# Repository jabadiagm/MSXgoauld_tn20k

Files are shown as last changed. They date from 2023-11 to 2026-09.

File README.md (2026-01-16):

# MSXgoauld_tn20k

> [WARNING]
> This repository is outdated and kept for reference only. Last version is here: https://github.com/jabadiagm/MSXgoauldSD_tn20k
>

MSX Goa'uld board with Tang Nano 20k

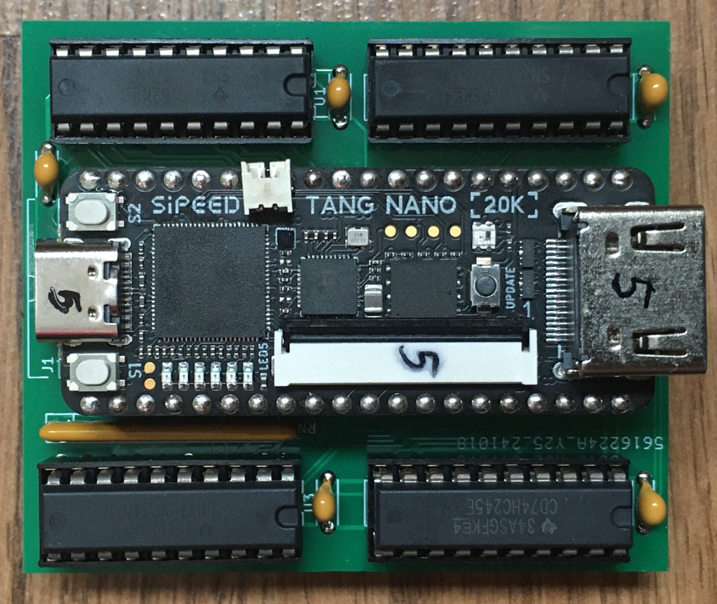
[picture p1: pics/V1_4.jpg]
V1.4_DIP

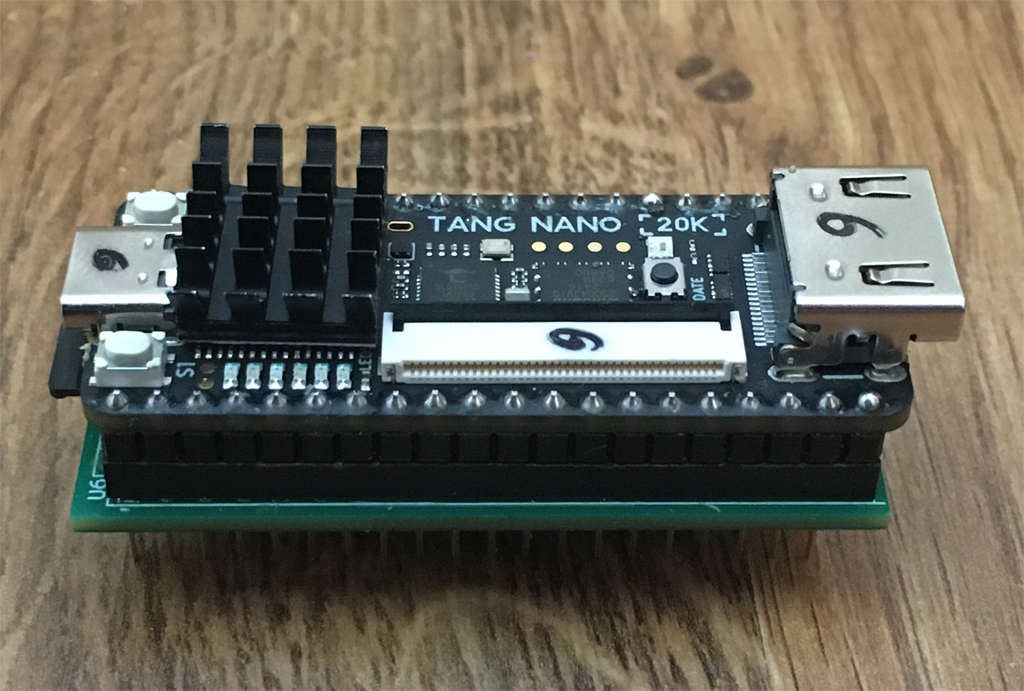
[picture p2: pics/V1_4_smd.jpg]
V1.4_SMD

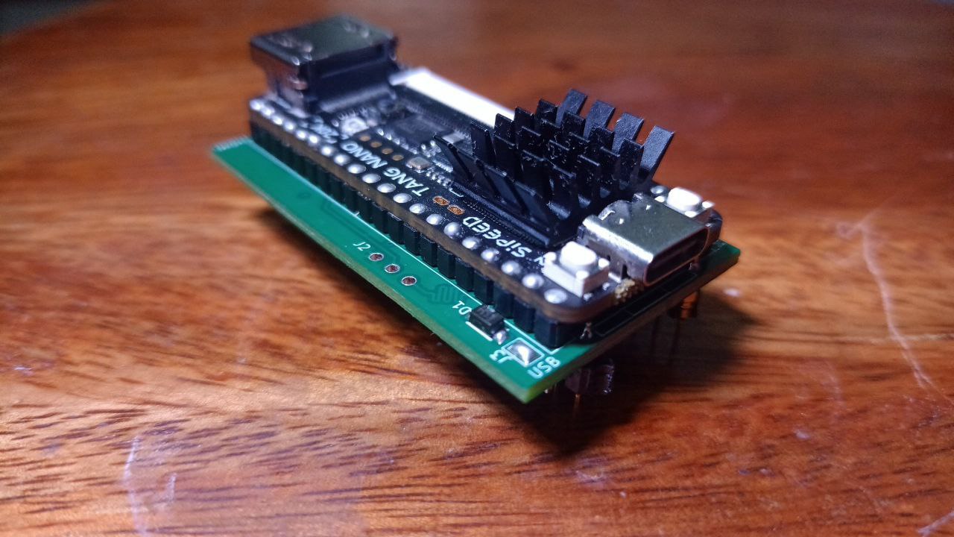
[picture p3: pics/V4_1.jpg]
V4.1_SMD


MSX2+ engine in Z80 socket. It turns one MSX into an MSX2+ by replacing Z80 processor. FPGA in board contains: 
* Z80
* V9958 with hdmi output
* MSX2+ BIOS
* 4MB mapper
* RTC
* PSG through hdmi
* OPLL through hdmi
* SCC (audio only) through hdmi

## How it works
Logic acts on bus control signals so that internal devices inside fpga take priority over external devices. 

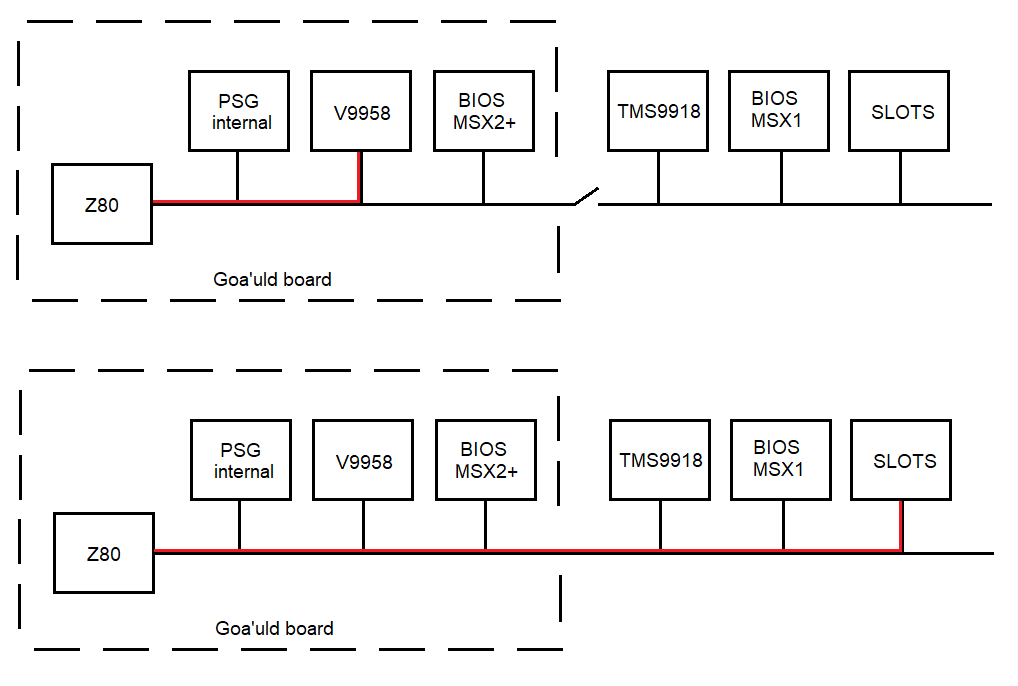
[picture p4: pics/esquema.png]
Esquema


## Boards

There are two lines of boards, 1.4 (by Palver, DIP & SMD) and 4.1 (by Chandler, SMD). Main difference is the orientation of the hdmi connector, to the same side of Z80's pin 1 (4.1) or the opposite (1.4). Revisions 2, 3, 4 are outdated and kept for reference only. 

Mind Revision 4.1 uses 74LVC245 in U5. Although their technical information tells they require 3.3V to operate, they are also 5V tolerant. This has been tested and considered safe. Check https://github.com/jabadiagm/MSXgoauld_tn20k/issues/15 for more information. 

BOM for the 1.4 DIP board:

```
Qty| Name                        | Ref
--------------------------------------------------
 2 | Latch                       | SN74HC373N
 2 | Bus transceiver             | SN74LVC245AN
 1 | Bus transceiver             | CD74HC245E
 6 | Capacitor 100 nF            | Aliexpress
 1 | Schottky Diode              | 1N5817
 1 | Resistor network 8x10K      | 4609X-101-103LF
 2 | Female header 20p 2.54      | Aliexpress
 1 | Male header 40p 2.54 turned | Aliexpress
 5 | Socket DIP 20               | ICVT-20P
 1 | Tang Nano 20K               | Aliexpress
 ```

## Slot map

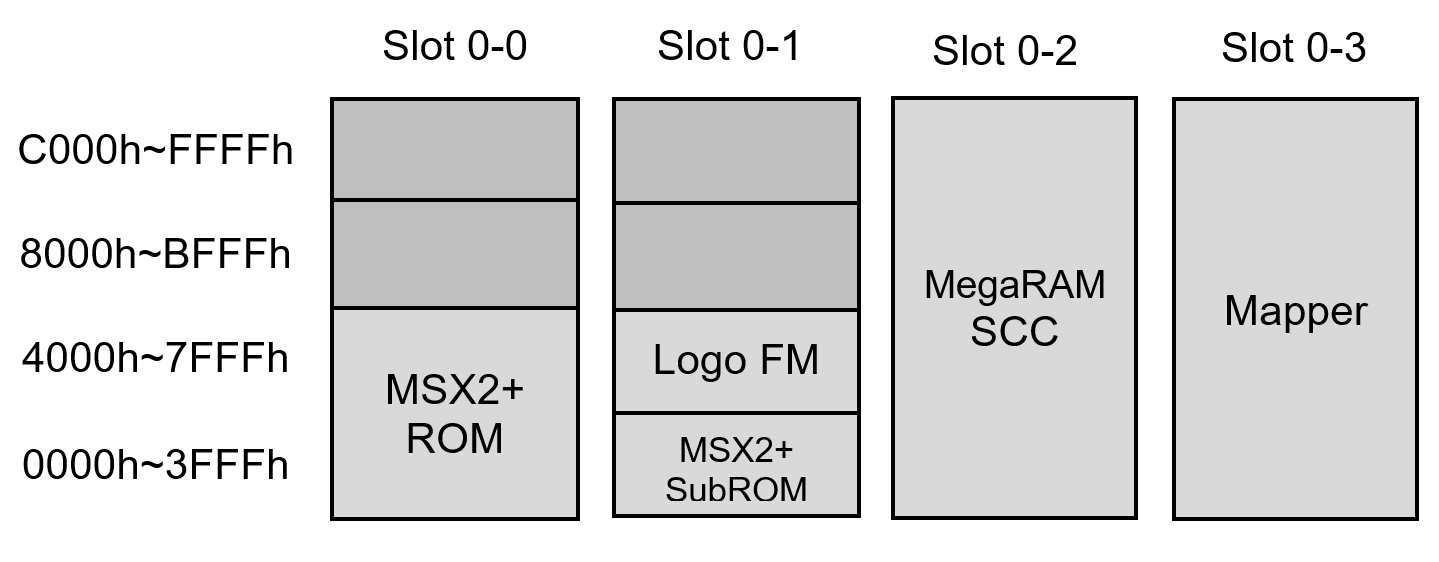
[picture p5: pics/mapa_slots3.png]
Slot map


Mapper can be relocated to slots 1, 2, or 3 using config menu.

## Update from previous hardware (V1, V2, V3, V4)
* Replace U1, U2 -> 74HC373, U5 -> 74HC245
* Solder a 10K resistor array to data bus lines, pulled up to 5V
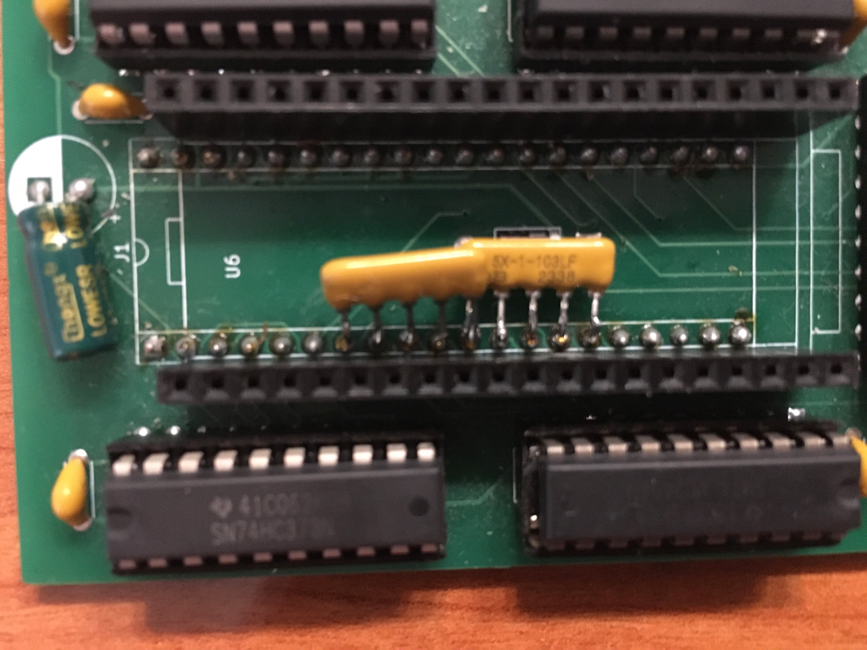
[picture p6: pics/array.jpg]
Array


## SCC audio
SCC is located in Slot 0-2 to use with sofarun, using these settings:

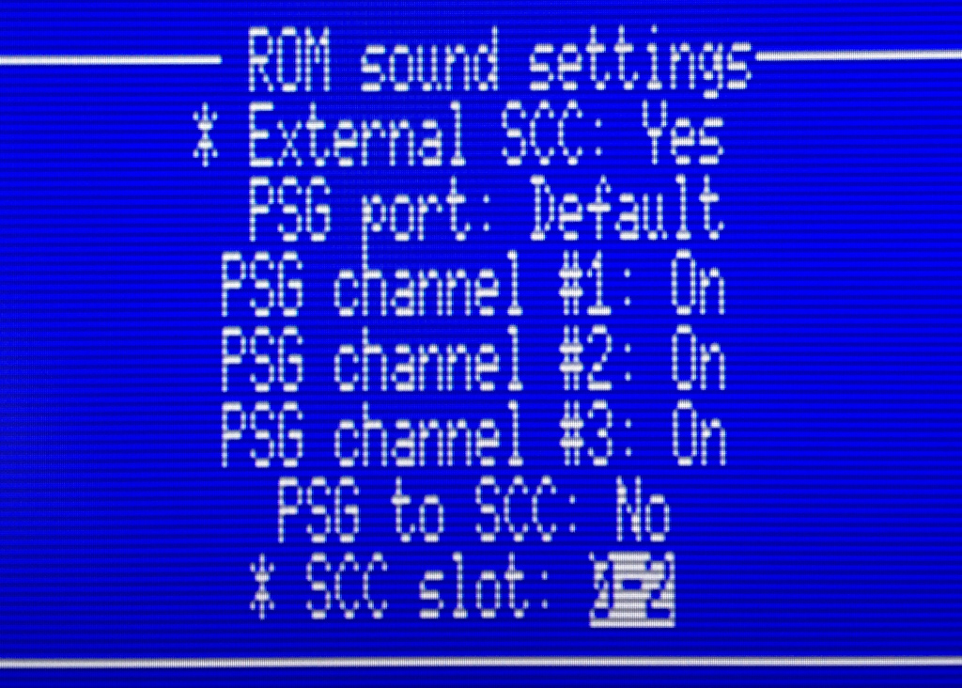
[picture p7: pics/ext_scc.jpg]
ext_scc


## Configuration
Config menu is showed pressing g during MSX logo. New improved menu is created by [nataliapc](https://github.com/nataliapc/msx_goauld_settings_menu)

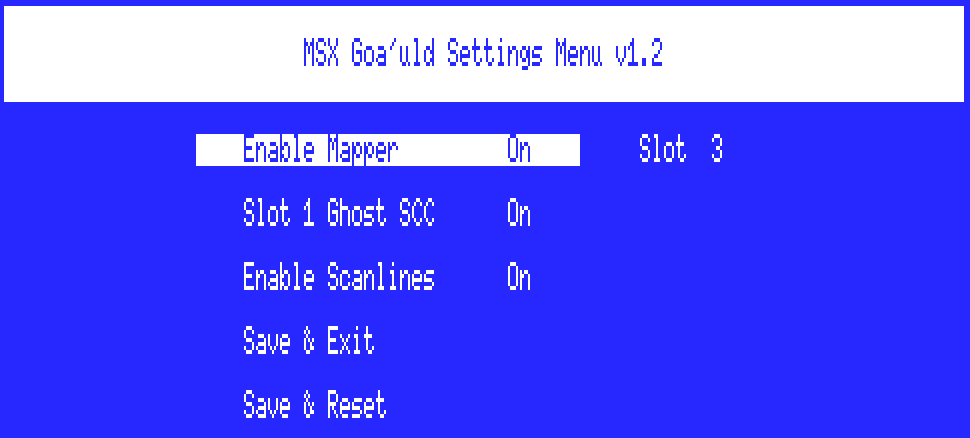
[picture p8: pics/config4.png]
Config


* Enable Mapper: On by default. Disable when having compatibility issues or to use a different mapper
* Mapper Slot: 0 by default. Change to 1-3 to get mapper in a not expanded slot (best compatibility). Physical slot will be disabled
* Slot 1 Ghost SCC: Off by default. Enable to get sound from an SCC cartridge located in slot 1
* Enable Scanlines: On by default. Disable to get a clean hdmi picture
* Save & Exit: store new config and continue, changes in mapper settings will be effective after pressing reset
* Save & Reset: store new config and make software reset, changes will be immediate

## Slots dance
Goa'uld has four internal slots available. As with other modules, internal slots take priority over physical ones. This means that when a device is using internal slot n, then physical slot n is disabled  and any cartridge in that slot will not be detected. 
By default, BIOS and mapper occupy internal slot 0, leaving physical slots 1 to 3 available for cartridges. However, this default layout can cause compatibility issues with some software, such as tape games. 
To resolve these issues, you can move the mapper from expanded slot 0 to one of the non-expanded internal slots (1, 2, or 3). This adjustment can solve many compatibility problems.

## Known issues
* Reset from config menu is not compatible with some hardware. Use physical reset button when possible
* Multimente: shows garbage characters. Move internal mapper to slots 1, 2 or 3
* Tape games fail: move internal mapper to slots 1, 2 or 3
* Noises when loading a rom with sofarun: change sofarun settings to use mapper for that rom
* Carnivore C2 software reset is not compatible with goa'uld

> [!WARNING]
> Not yet fully working on all MSX!
>

## HDMI wiring
Use a flat cable with detachable connectors, like [this](https://a.aliexpress.com/_Ex8dto0) or [this](https://s.click.aliexpress.com/e/_oEFYFU9)

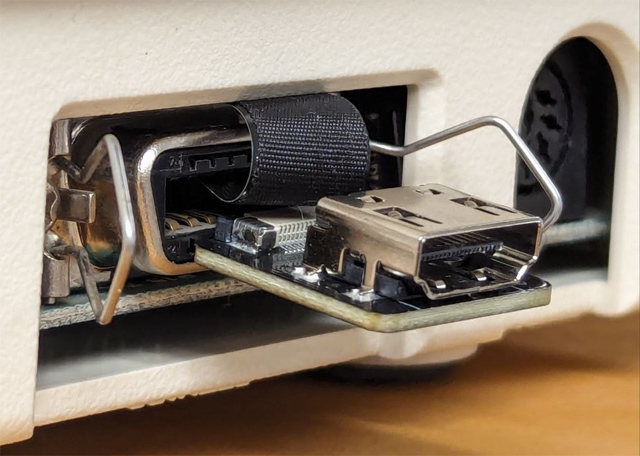
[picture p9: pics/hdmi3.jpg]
hdmi


Find some examples [here](https://makerworld.com/es/models/1246988-hdmi-cover-using-printer-port-for-msx-goauld) and [here](https://www.thingiverse.com/thing:6990854)

Toshiba HX-10 has proven to be a nice choice for Goa'uld board. There are some mods to get hdmi connector and even a reset button on the side panel. An example [here](https://www.thingiverse.com/thing:6932728)

### Tips
* Try a proven board first to check if your msx is compatible
* Get integrated circuits from trusted sources
* Use a heatsink when possible
* Use turned pins in header to avoid damages in Z80 socket
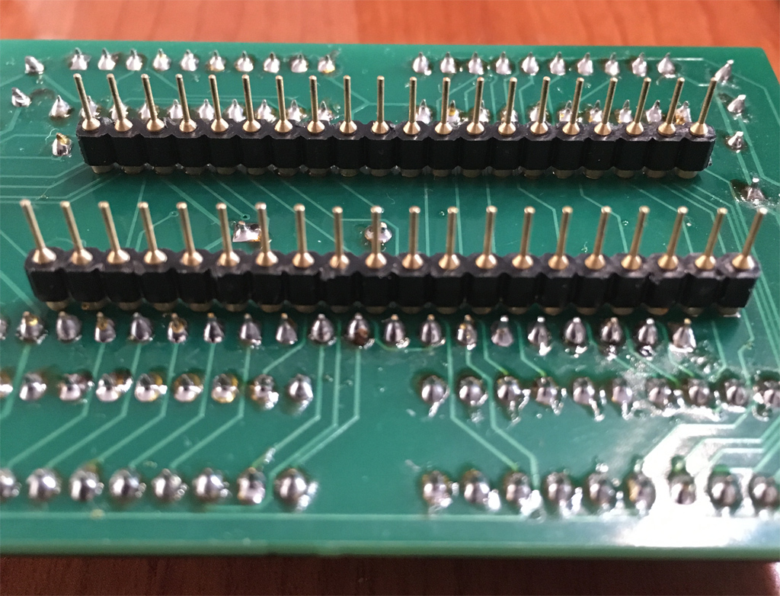
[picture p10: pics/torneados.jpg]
turned header

* Board is sensitive to dirty electrical contacts, way more than Z80. Keep cartridge & Z80 socket contacts clean
* When soldering headers, start with the inner one (Z80)
* When using an extension wire, plug tang to 5V

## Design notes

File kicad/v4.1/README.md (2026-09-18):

# Revision 4.1

4.1 Revision shrinks revision 4.0 by removing the external voltage regulator, which is not necessary anymore. This revision also adds 100nF decoupling capacitors for buffers/latches ICs and places pull-up resistors for data bus wires.

V4.1_SMD

## BOM

Check our [Interactive BOM](https://html-preview.github.io/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) to have better details.                                                       

| Reference | Chip | Value |
|:-----:|:-----:|:-----:|
| U1~U2 | 74HCT373 (TSSOP-20) | - |
| U3~U4 | 74LVC245 (TSSOP-20) | - |
| U5 | 74HC245 (TSSOP-20) | - |
| U6 | Tang Nano 20k | - |
| D1* | DSS32 (SOD123FL) | - |
| C4~C8 | 0603 SMD Capacitor | $\mathsf{100\ nF}$ |
| R1 | Resistor (0603) | $\mathsf{10\ k\Omega}$ |
| R2~R3 | 4xResistor Array (0603) | $\mathsf{16\ k\Omega}$ |

## Assembly

Production files (gerbers, assembly, placement...) can be found in `production` folder

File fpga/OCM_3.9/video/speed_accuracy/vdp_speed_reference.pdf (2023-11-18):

“MOST COMMON REFERENCE FOR THE VDP SPEED ACCURACY”

PANASONIC FS-A1GT MSX turbo R / R800 (Z80 MODE) / VDP V9958

The tables for the copies:

LMMM accuracy: 16 | HMMM accuracy: 32 | YMMM accuracy: 32
TESTCOPY FS-A1GT X=32 | TESTCOPY FS-A1GT X=64 | TESTCOPY FS-A1GT X=64
Spr / Lin - Speed 50/60Hz | Spr / Lin - Speed 50/60Hz | Spr / Lin - Speed 50/60Hz
on / 212 - 1232 / 976 | on / 212 - 3520 / 2784 | on / 212 - 4192 / 3168
on / 192 - 1264 / 1008 | on / 192 - 3616 / 2880 | on / 192 - 4384 / 3360
off / 212 - 1584 / 1312 | off / 212 - 4352 / 3616 | off / 212 - 5856 / 4832
off / 192 - 1584 / 1312 | off / 192 - 4384 / 3648 | off / 192 - 5856 / 4864
--Blank-- - 1600 / 1328 | --Blank-- - 4512 / 3744 | --Blank-- - 6112 / 5120

The tables for the fills:

LMMV accuracy: 16 | HMMV accuracy: 64
TESTCOPY FS-A1GT X=32 | TESTCOPY FS-A1GT X=128
Spr / Lin - Speed 50/60Hz | Spr / Lin - Speed 50/60Hz
on / 212 - 1696 / 1344 | on / 212 - 7040 / 5632
on / 192 - 1728 / 1392 | on / 192 - 7168 / 5760
off / 212 - 1840 / 1488 | off / 212 - 7232 / 5888
off / 192 - 1856 / 1504 | off / 192 - 7360 / 5952
--Blank-- - 2128 / 1776 | --Blank-- - 8448 / 7040

The table for the lines:

LINE accuracy: 32
TESTCOPY FS-A1GT X=8 Y=8

Spr / Lin - Speed 50/60Hz

on / 212 - | 3936 | / | 3264
on / 192 - | 3968 | / | 3296
off / 212 - | 4096 | / | 3392
off / 192 - | 4096 | / | 3392
--Blank-- - | 4224 | / | 3520
( on / 212 )

Notes:

- Speed is indicated in bytes per interrupt.
- On “TestCopy” program LINES = SPEED / ACCURACY.
- The CPU frequency for the test is 3.58MHz.

The above values have been verified by KdL, 2018.05.14 These information refers to: http://map.grauw.nl/articles/vdp_commands_speed.php

More information to get the most accurate LINE speed (not yet implemented in OCM): http://map.grauw.nl/articles/vdp-vram-timing/vdp-timing.htmlhttp://map.grauw.nl/articles/vdp-vram-timing/vdp-timing-2.html

“MOST COMMON REFERENCE FOR THE VDP SPEED ACCURACY”

PHILIPS NMS-8245 MSX2 / Z80 / VDP V9938

The tables for the copies:

LMMM accuracy: 16 | HMMM accuracy: 32 | YMMM accuracy: 32
TESTCOPY NMS-8245 X=32 | TESTCOPY NMS-8245 X=64 | TESTCOPY NMS-8245 X=64
Spr / Lin - Speed 50/60Hz | Spr / Lin - Speed 50/60Hz | Spr / Lin - Speed 50/60Hz
on / 212 - 1232 / 976 | on / 212 - 3520 / 2784 | on / 212 - 4192 / 3168
on / 192 - 1264 / 1008 | on / 192 - 3616 / 2880 | on / 192 - 4384 / 3360
off / 212 - 1584 / 1312 | off / 212 - 4352 / 3616 | off / 212 - 5856 / 4832
off / 192 - 1584 / 1312 | off / 192 - 4384 / 3648 | off / 192 - 5856 / 4864
--Blank-- - 1600 / 1328 | --Blank-- - 4512 / 3744 | --Blank-- - 6112 / 5120

The tables for the fills:

LMMV accuracy: 16 | HMMV accuracy: 64
TESTCOPY NMS-8245 X=32 | TESTCOPY NMS-8245 X=128
Spr / Lin - Speed 50/60Hz | Spr / Lin - Speed 50/60Hz
on / 212 - 1696 / 1344 | on / 212 - 7040 / 5632
on / 192 - 1728 / 1392 | on / 192 - 7168 / 5760
off / 212 - 1840 / 1488 | off / 212 - 7232 / 5888
off / 192 - 1856 / 1504 | off / 192 - 7360 / 5952
--Blank-- - 2128 / 1776 | --Blank-- - 8448 / 7040

The table for the lines:

LINE accuracy: 32
TESTCOPY NMS-8245 X=8 Y=8

Spr / Lin - Speed 50/60Hz

on / 212 - | 4096 | / | 3392
on / 192 - | 4128 | / | 3424
off / 212 - | 4224 | / | 3520
off / 192 - | 4256 | / | 3520
--Blank-- - | 4352 | / | 3648
( on / 212 )

Notes:

- Speed is indicated in bytes per interrupt.
- On “TestCopy” program LINES = SPEED / ACCURACY.
- The CPU frequency for the test is 3.58MHz.

The above values have been verified by KdL, 2018.05.14 These information refers to: http://map.grauw.nl/articles/vdp_commands_speed.php

More information to get the most accurate LINE speed (not yet implemented in OCM): http://map.grauw.nl/articles/vdp-vram-timing/vdp-timing.htmlhttp://map.grauw.nl/articles/vdp-vram-timing/vdp-timing-2.html

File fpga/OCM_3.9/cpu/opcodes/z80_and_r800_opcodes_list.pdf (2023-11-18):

## Z80 And R800 Opcodes List

### Opcodes on single-byte

| 00 | 01 | 02 | 03 | 04 | 05 | 06 | 07 | 08 | 09 | 0A | 0B | 0C | 0D | 0E | 0F
00 | NOP | LD BC,ad | LD (BC),A | INC BC | INC B | DEC B | LD B,v | RLCA | EX AF,AF' | ADD HL,BC | LD A,(BC) | DEC BC | INC C | DEC C | LD C,v | RRCA
10 | DJNZ v | LD DE,ad | LD (DE),A | INC DE | INC D | DEC D | LD D,v | RLA | JR v | ADD HL,DE | LD A,(DE) | DEC DE | INC E | DEC E | LD E,v | RRA
20 | JR nz,v | LD HL,ad | LD (ad),HL | INC HL | INC H | DEC H | LD H,v | DAA | JR z,v | ADD HL,HL | LD HL,(ad) | DEC HL | INC L | DEC L | LD L,v | CPL
30 | JR nc,v | LD SP,ad | LD (ad),A | INC SP | INC (HL) | DEC (HL) | LD (HL),v | SCF | JR C,v | ADD HL,SP | LD A,(ad) | DEC SP | INC A | DEC A | LD A,v | CCF
40 | LD B,B | LD B,C | LD B,D | LD B,E | LD B,H | LD B,L | LD B,(HL) | LD B,A | LD C,B | LD C,C | LD C,D | LD C,E | LD C,H | LD C,L | LD C,(HL) | LD C,A
50 | LD D,B | LD D,C | LD D,D | LD D,E | LD D,H | LD D,L | LD D,(HL) | LD D,A | LD E,B | LD E,C | LD E,D | LD E,E | LD E,H | LD E,L | LD E,(HL) | LD E,A
60 | LD H,B | LD H,C | LD H,D | LD H,E | LD H,H | LD H,L | LD H,(HL) | LD H,A | LD L,B | LD L,C | LD L,D | LD L,E | LD L,H | LD L,L | LD L,(HL) | LD L,A
70 | LD (HL),B | LD (HL),C | LD (HL),D | LD (HL),E | LD (HL),H | LD (HL),L | HALT | LD (HL),A | LD A,B | LD A,C | LD A,D | LD A,E | LD A,H | LD A,L | LD A,(HL) | LD A,A
80 | ADD A,B | ADD A,C | ADD A,D | ADD A,E | ADD A,H | ADD A,L | ADD A,(HL) | ADD A,A | ADC A,B | ADC A,C | ADC A,D | ADC A,E | ADC A,H | ADC A,L | ADC A,(HL) | ADC A,A
90 | SUB B | SUB C | SUB D | SUB E | SUB H | SUB L | SUB (HL) | SUB A | SBC A,B | SBC A,C | SBC A,D | SBC A,E | SBC A,H | SBC A,L | SBC A,(HL) | SBC A
A0 | AND B | AND C | AND D | AND E | AND H | AND L | AND (HL) | AND A | XOR B | XOR C | XOR D | XOR E | XOR H | XOR L | XOR (HL) | XOR A
B0 | OR B | OR C | OR D | OR E | OR H | OR L | OR (HL) | OR A | CP B | CP C | CP D | CP E | CP H | CP L | CP (HL) | CP A
C0 | RET nz | POP BC | JP nz,ad | JP ad | CALL nz,ad | PUSH BC | ADD A,v | RST 0h | RET z | RET | JP z,ad | * | CALL z,ad | CALL ad | ADC A,v | RST 8h
D0 | RET nc | POP DE | JP nc,ad | OUT (v),A | CALL nc,ad | PUSH DE | SUB v | RST 10h | RET c | EXX | JP c,ad | IN A,(v) | CALL c,ad | ** | SBC A,v | RST 18h
E0 | RET po | POP HL | JP po,ad | EX (SP),HL | CALL po,ad | PUSH HL | AND v | RST 20h | RET pe | JP (HL) | JP pe,ad | EX DE,HL | CALL pe,ad | *** | XOR v | RST 28h
F0 | RET p | POP AF | JP p,ad | DI | CALL p,ad | PUSH AF | OR v | RST 30h | RET m | LD SP,HL | JP m,ad | EI | CALL m,ad | **** | CP v | RST 38h

Note: Some of these opcodes are followed by one or two bytes to specify the value v or the address ad.

### (*) Opcodes extended on 2-byte which begin with CBh

CB | 00 | 01 | 02 | 03 | 04 | 05 | 06 | 07 | 08 | 09 | 0A | 0B | 0C | 0D | 0E | 0F
00 | RLC B | RLC C | RLC D | RLC E | RLC H | RLC L | RLC (HL) | RLC A | RRC B | RRC C | RRC D | RRC E | RRC H | RRC H | RRC (HL) | RRC A
10 | RL B | RL C | RL D | RL E | RL H | RL L | RL (HL) | RL A | RR B | RR C | RR D | RR E | RR H | RR H | RR (HL) | RR A
20 | SLA B | SLA C | SLA D | SLA E | SLA H | SLA L | SLA (HL) | SLA A | SRA B | SRA C | SRA D | SRA E | SRA H | SRA H | SRA (HL) | SRA A
30 | SLL B | SLL C | SLL D | SLL E | SLL H | SLL L | SLL (HL) | SLL A | SRL B | SRL C | SRL D | SRL E | SRL H | SRL H | SRL (HL) | SRL A
40 | BIT 0,B | BIT 0,C | BIT 0,D | BIT 0,E | BIT 0,H | BIT 0,L | BIT 0,(HL) | BIT 0,A | BIT 1,B | BIT 1,C | BIT 1,D | BIT 1,E | BIT 1,H | BIT 1,L | BIT 1,(HL) | BIT 1,A
50 | BIT 2,B | BIT 2,C | BIT 2,D | BIT 2,E | BIT 2,H | BIT 2,L | BIT 2,(HL) | BIT 2,A | BIT 3,B | BIT 3,C | BIT 3,D | BIT 3,E | BIT 3,H | BIT 3,L | BIT 3,(HL) | BIT 3,A
60 | BIT 4,B | BIT 4,C | BIT 4,D | BIT 4,E | BIT 4,H | BIT 4,L | BIT 4,(HL) | BIT 4,A | BIT 5,B | BIT 5,C | BIT 5,D | BIT 5,E | BIT 5,H | BIT 5,L | BIT 5,(HL) | BIT 5,A
70 | BIT 6,B | BIT 6,C | BIT 6,D | BIT 6,E | BIT 6,H | BIT 6,L | BIT 6,(HL) | BIT 6,A | BIT 7,B | BIT 7,C | BIT 7,D | BIT 7,E | BIT 7,H | BIT 7,L | BIT 7,(HL) | BIT 7,A
80 | RES 0,B | RES 0,C | RES 0,D | RES 0,E | RES 0,H | RES 0,L | RES 0,(HL) | RES 0,A | RES 1,B | RES 1,C | RES 1,D | RES 1,E | RES 1,H | RES 1,L | RES 1,(HL) | RES 1,A
90 | RES 2,B | RES 2,C | RES 2,D | RES 2,E | RES 2,H | RES 2,L | RES 2,(HL) | RES 2,A | RES 3,B | RES 3,C | RES 3,D | RES 3,E | RES 3,H | RES 3,L | RES 3,(HL) | RES 3,A
A0 | RES 4,B | RES 4,C | RES 4,D | RES 4,E | RES 4,H | RES 4,L | RES 4,(HL) | RES 4,A | RES 5,B | RES 5,C | RES 5,D | RES 5,E | RES 5,H | RES 5,L | RES 5,(HL) | RES 5,A
B0 | RES 6,B | RES 6,C | RES 6,D | RES 6,E | RES 6,H | RES 6,L | RES 6,(HL) | RES 6,A | RES 7,B | RES 7,C | RES 7,D | RES 7,E | RES 7,H | RES 7,L | RES 7,(HL) | RES 7,A
C0 | SET 0,B | SET 0,C | SET 0,D | SET 0,E | SET 0,H | SET 0,L | SET 0,(HL) | SET 0,A | SET 1,B | SET 1,C | SET 1,D | SET 1,E | SET 1,H | SET 1,L | SET 1,(HL) | SET 1,A
D0 | SET 2,B | SET 2,C | SET 2,D | SET 2,E | SET 2,H | SET 2,L | SET 2,(HL) | SET 2,A | SET 3,B | SET 3,C | SET 3,D | SET 3,E | SET 3,H | SET 3,L | SET 3,(HL) | SET 3,A
E0 | SET 4,B | SET 4,C | SET 4,D | SET 4,E | SET 4,H | SET 4,L | SET 4,(HL) | SET 4,A | SET 5,B | SET 5,C | SET 5,D | SET 5,E | SET 5,H | SET 5,L | SET 5,(HL) | SET 5,A
F0 | SET 6,B | SET 6,C | SET 6,D | SET 6,E | SET 6,H | SET 6,L | SET 6,(HL) | SET 6,A | SET 7,B | SET 7,C | SET 7,D | SET 7,E | SET 7,H | SET 7,L | SET 7,(HL) | SET 7,A

### (**) Opcodes extended on two-byte which begin with DDh (for register IX)

DD | 00 | 01 | 02 | 03 | 04 | 05 | 06 | 07 | 08 | 09 | 0A | 0B | 0C | 0D | 0E | 0F
00 | | | | | | | | | | ADD IX,BC
10 | | | | | | | | | | ADD IX,DE
20 | | LD IX,ad | LD (ad),IX | INC IX | INC IXH | DEC IXH | LD IXH,v | | | ADD IX,IX | LD IX,(ad) | DEC IX | INC IXL | DEC IXL | LD IXL,v
30 | | | | | INC (IX+v) | DEC (IX+v) | LD (IX+v),v | | | ADD IX,SP
40 | | | | | LD B,IXH | LD B,IXL | LD B,(IX+v) | | | | | | LD C,IXH | LD C,IXL | LD C,(IX+v)
50 | | | | | LD D,IXH | LD D,IXL | LD D,(IX+v) | | | | | | LD E,IXH | LD E,IXL | LD E,(IX+v)
60 | LD IXH,B | LD IXH,C | LD IXH,D | LD IXH,E | LD IXH,IXH | LD IXH,IXL | LD H,(IX+v) | LD IXH,A | LD IXL,B | LD IXL,C | LD IXL,D | LD IXL,E | LD IXL,IXH | LD IXL,IXL | LD L,(IX+v) | LD IXL,A
70 | LD (IX+v),B | LD (IX+v),C | LD (IX+v),D | LD (IX+v),E | LD (IX+v),H | LD (IX+v),L | | LD (IX+v),A | | | | | LD A,IXH | LD A,IXL | LD A,(IX+v)
80 | | | | | ADD A,IXH | ADD A,IXL | ADD A,(IX+v) | | | | | | ADC A,IXH | ADC A,IXL | ADC A,(IX+v)
90 | | | | | SUB IXH | SUB IXL | SUB (IX+v) | | | | | | SBC A,IXH | SBC A,IXL | SBC A,(IX+v)
A0 | | | | | AND IXH | AND IXL | AND (IX+v) | | | | | | XOR IXH | XOR IXL | XOR (IX+v)
B0 | | | | | OR IXH | OR IXL | OR (IX+v) | | | | | | CP IXH | CP IXL | CP (IX+v)
C0 | | | | | | | | | | | | **²

D0
E0 | | POP IX | | EX (SP),IX | | PUSH IX | | | | JP (IX)
F0 | | | | | | | | | | LD SP,IX

Note: Some of these opcodes are followed by one or two bytes to specify the value v or the address ad.

### (**²) Opcodes extended on four-byte which begin with DDh+CBh+v (for register IX)

DD+CB+v | 00 | 01 | 02 | 03 | 04 | 05 | 06 | 07 | 08 | 09 | 0A | 0B | 0C | 0D | 0E | 0F
00 | RLC (v+IX) LD B,(v+IX) | RLC (IX+v) LD C,(IX+v) | RLC (v+IX) LD D,(v+IX) | RLC (v+IX) LD E,(v+IX) | RLC (v+IX) LD H,(v+IX) | RLC (v+IX) LD L,(v+IX) | RLC (v+IX) | RLC (v+IX) LD A,(v+IX) | RRC (v+IX) LD B,(v+IX) | RRC (v+IX) LD C,(v+IX) | RRC (v+IX) LD D,(v+IX) | RRC (v+IX) LD E,(v+IX) | RRC (v+IX) LD H,(v+IX) | RRC (v+IX) LD L,(v+IX) | RRC (v+IX) | RRC (v+IX) LD A,(v+IX)
10 | RL (v+IX) LD B,(v+IX) | RL (IX+v) LD C,(IX+v) | RL (v+IX) LD D,(v+IX) | RL (v+IX) LD E,(v+IX) | RL (v+IX) LD H,(v+IX) | RL (v+IX) LD L,(v+IX) | RL (v+IX) | RL (v+IX) LD A,(v+IX) | RR (v+IX) LD B,(v+IX) | RR (v+IX) LD C,(v+IX) | RR (v+IX) LD D,(v+IX) | RR (v+IX) LD E,(v+IX) | RR (v+IX) LD H,(v+IX) | LD L,(v+IX) RR (v+IX) | RR (v+IX) | RR (v+IX) LD A,(v+IX)
20 | SLA (v+IX) LD B,(v+IX) | SLA (IX+v) LD C,(IX+v) | SLA (v+IX) LD D,(v+IX) | SLA (v+IX) LD E,(v+IX) | SLA (v+IX) LD H,(v+IX) | SLA (v+IX) LD L,(v+IX) | SLA (v+IX) | SLA (v+IX) LD A,(v+IX) | SRA (v+IX) LD B,(v+IX) | SRA (v+IX) LD C,(v+IX) | SRA (v+IX) LD D,(v+IX) | SRA (v+IX) LD E,(v+IX) | SRA (v+IX) LD H,(v+IX) | SRA (v+IX) LD L,(v+IX) | SRA (v+IX) | SRA (v+IX) LD A,(v+IX)
30 | SLL (v+IX) LD B,(v+IX) | SLL (IX+v) LD C,(IX+v) | SLL (v+IX) LD D,(v+IX) | SLL (v+IX) LD E,(v+IX) | SLL (v+IX) LD H,(v+IX) | SLL (v+IX) LD L,(v+IX) | SLL (v+IX) | SRL (v+IX) LD A,(v+IX) | SRL (v+IX) LD B,(v+IX) | SRL (v+IX) LD C,(v+IX) | SRL (v+IX) LD D,(v+IX) | SRL (v+IX) LD E,(v+IX) | SRL (v+IX) LD H,(v+IX) | SRL (v+IX) LD L,(v+IX) | SRL (v+IX) | SRL (v+IX) LD A,(v+IX)
40 | BIT 0,(v+IX) LD B,(v+IX) | BIT 0,(IX+v) LD C,(IX+v) | BIT 0,(v+IX) LD D,(v+IX) | BIT 0,(v+IX) LD E,(v+IX) | BIT 0,(v+IX) LD H,(v+IX) | BIT 0,(v+IX) LD L,(v+IX) | BIT 0, (v+IX) | BIT 0,(v+IX) LD A,(v+IX) | BIT 1,(v+IX) LD B,(v+IX) | BIT 1,(v+IX) LD C,(v+IX) | BIT 1,(v+IX) LD D,(v+IX) | BIT 1,(v+IX) LD E,(v+IX) | BIT 1,(v+IX) LD H,(v+IX) | BIT 1,(v+IX) LD L,(v+IX) | BIT 1, (v+IX) | BIT 1,(v+IX) LD A,(v+IX)
50 | BIT 2,(v+IX) LD B,(v+IX) | BIT 2,(IX+v) LD C,(IX+v) | BIT 2,(v+IX) LD D,(v+IX) | BIT 2,(v+IX) LD E,(v+IX) | BIT 2,(v+IX) LD H,(v+IX) | BIT 2,(v+IX) LD L,(v+IX) | BIT 2, (v+IX) | BIT 2,(v+IX) LD A,(v+IX) | BIT 3,(v+IX) LD B,(v+IX) | BIT 3,(v+IX) LD C,(v+IX) | BIT 3,(v+IX) LD D,(v+IX) | BIT 3,(v+IX) LD E,(v+IX) | BIT 3,(v+IX) LD H,(v+IX) | BIT 3,(v+IX) LD L,(v+IX) | BIT 3, (v+IX) | BIT 3,(v+IX) LD A,(v+IX)
60 | BIT 4,(v+IX) LD B,(v+IX) | BIT 4,(IX+v) LD C,(IX+v) | BIT 4,(v+IX) LD D,(v+IX) | BIT 4,(v+IX) LD E,(v+IX) | BIT 4,(v+IX) LD H,(v+IX) | BIT 4,(v+IX) LD L,(v+IX) | BIT 4, (v+IX) | BIT 4,(v+IX) LD A,(v+IX) | BIT 5,(v+IX) LD B,(v+IX) | BIT 5,(v+IX) LD C,(v+IX) | BIT 5,(v+IX) LD D,(v+IX) | BIT 5,(v+IX) LD E,(v+IX) | BIT 5,(v+IX) LD H,(v+IX) | BIT 5,(v+IX) LD L,(v+IX) | BIT 5, (v+IX) | BIT 5,(v+IX) LD A,(v+IX)
70 | BIT 6,(v+IX) LD B,(v+IX) | BIT 6,(IX+v) LD C,(IX+v) | BIT 6,(v+IX) LD D,(v+IX) | BIT 6,(v+IX) LD E,(v+IX) | BIT 6,(v+IX) LD H,(v+IX) | BIT 6,(v+IX) LD L,(v+IX) | BIT 6, (v+IX) | BIT 6,(v+IX) LD A,(v+IX) | BIT 7,(v+IX) LD B,(v+IX) | BIT 7,(v+IX) LD C,(v+IX) | BIT 7,(v+IX) LD D,(v+IX) | BIT 7,(v+IX) LD E,(v+IX) | BIT 7,(v+IX) LD H,(v+IX) | BIT 7,(v+IX) LD L,(v+IX) | BIT 7, (v+IX) | BIT 7,(v+IX) LD A,(v+IX)
80 | RES 0,(v+IX) LD B,(v+IX) | RES 0,(IX+v) LD C,(IX+v) | RES 0,(v+IX) LD D,(v+IX) | RES 0,(v+IX) LD E,(v+IX) | RES 0,(v+IX) LD H,(v+IX) | RES 0,(v+IX) LD L,(v+IX) | RES 0, (v+IX) | RES 0,(v+IX) LD A,(v+IX) | RES 1,(v+IX) LD B,(v+IX) | RES 1,(v+IX) LD C,(v+IX) | RES 1,(v+IX) LD D,(v+IX) | RES 1,(v+IX) LD E,(v+IX) | RES 1,(v+IX) LD H,(v+IX) | RES 1,(v+IX) LD L,(v+IX) | RES 1, (v+IX) | RES 1,(v+IX) LD A,(v+IX)
90 | RES 2,(v+IX) LD B,(v+IX) | RES 2,(IX+v) LD C,(IX+v) | RES 2,(v+IX) LD D,(v+IX) | RES 2,(v+IX) LD E,(v+IX) | RES 2,(v+IX) LD H,(v+IX) | BIT 2,(v+IX) LD L,(v+IX) | RES 2, (v+IX) | RES 2,(v+IX) LD A,(v+IX) | RES 3,(v+IX) LD B,(v+IX) | RES 3,(v+IX) LD C,(v+IX) | RES 3,(v+IX) LD D,(v+IX) | RES 3,(v+IX) LD E,(v+IX) | RES 3,(v+IX) LD H,(v+IX) | RES 3,(v+IX) LD L,(v+IX) | RES 3, (v+IX) | RES 3,(v+IX) LD A,(v+IX)
A0 | RES 4,(v+IX) LD B,(v+IX) | RES 4,(IX+v) LD C,(IX+v) | RES 4,(v+IX) LD D,(v+IX) | RES 4,(v+IX) LD E,(v+IX) | RES 4,(v+IX) LD H,(v+IX) | RES 4,(v+IX) LD L,(v+IX) | RES 4, (v+IX) | RES 4,(v+IX) LD A,(v+IX) | RES 5,(v+IX) LD B,(v+IX) | RES 5,(v+IX) LD C,(v+IX) | RES 5,(v+IX) LD D,(v+IX) | RES 5,(v+IX) LD E,(v+IX) | RES 5,(v+IX) LD H,(v+IX) | RES 5,(v+IX) LD L,(v+IX) | RES 5, (v+IX) | RES 5,(v+IX) LD A,(v+IX)
B0 | RES 6,(v+IX) LD B,(v+IX) | RES 6,(IX+v) LD C,(IX+v) | RES 6,(v+IX) LD D,(v+IX) | RES 6,(v+IX) LD E,(v+IX) | RES 6,(v+IX) LD H,(v+IX) | RES 6,(v+IX) LD L,(v+IX) | RES 6, (v+IX) | RES 6,(v+IX) LD A,(v+IX) | RES 7,(v+IX) LD B,(v+IX) | RES 7,(v+IX) LD C,(v+IX) | RES 7,(v+IX) LD D,(v+IX) | RES 7,(v+IX) LD E,(v+IX) | RES 7,(v+IX) LD H,(v+IX) | RES 7,(v+IX) LD L,(v+IX) | RES 7, (v+IX) | RES 7,(v+IX) LD A,(v+IX)
C0 | SET 0,(v+IX) LD B,(v+IX) | SET 0,(IX+v) LD C,(IX+v) | SET 0,(v+IX) LD D,(v+IX) | SET 0,(v+IX) LD E,(v+IX) | SET 0,(v+IX) LD H,(v+IX) | SET 0,(v+IX) LD L,(v+IX) | SET 0, (v+IX) | SET 0,(v+IX) LD A,(v+IX) | SET 1,(v+IX) LD B,(v+IX) | SET 1,(v+IX) LD C,(v+IX) | SET 1,(v+IX) LD D,(v+IX) | SET 1,(v+IX) LD E,(v+IX) | SET 1,(v+IX) LD H,(v+IX) | SET 1,(v+IX) LD L,(v+IX) | SET 1, (v+IX) | SET 1,(v+IX) LD A,(v+IX)
D0 | SET 2,(v+IX) LD B,(v+IX) | SET 2,(IX+v) LD C,(IX+v) | SET 2,(v+IX) LD D,(v+IX) | SET 2,(v+IX) LD E,(v+IX) | SET 2,(v+IX) LD H,(v+IX) | SET 2,(v+IX) LD L,(v+IX) | SET 2, (v+IX) | SET 2,(v+IX) LD A,(v+IX) | SET 3,(v+IX) LD B,(v+IX) | SET 3,(v+IX) LD C,(v+IX) | SET 3,(v+IX) LD D,(v+IX) | SET 3,(v+IX) LD E,(v+IX) | SET 3,(v+IX) LD H,(v+IX) | SET 3,(v+IX) LD L,(v+IX) | SET 3, (v+IX) | SET 3,(v+IX) LD A,(v+IX)
E0 | SET 4,(v+IX) LD B,(v+IX) | SET 4,(IX+v) LD C,(IX+v) | SET 4,(v+IX) LD D,(v+IX) | SET 4,(v+IX) LD E,(v+IX) | SET 4,(v+IX) LD H,(v+IX) | SET 4,(v+IX) LD L,(v+IX) | SET 4, (v+IX) | SET 4,(v+IX) LD A,(v+IX) | SET 5,(v+IX) LD B,(v+IX) | SET 5,(v+IX) LD C,(v+IX) | SET 5,(v+IX) LD D,(v+IX) | SET 5,(v+IX) LD E,(v+IX) | SET 5,(v+IX) LD H,(v+IX) | SET 5,(v+IX) LD L,(v+IX) | SET 5, (v+IX) | SET 5,(v+IX) LD A,(v+IX)
F0 | SET 6,(v+IX) LD B,(v+IX) | SET 6,(IX+v) LD C,(IX+v) | SET 6,(v+IX) LD D,(v+IX) | SET 6,(v+IX) LD E,(v+IX) | SET 6,(v+IX) LD H,(v+IX) | SET 6,(v+IX) LD L,(v+IX) | SET 6, (v+IX) | SET 6,(v+IX) LD A,(v+IX) | SET 7,(v+IX) LD B,(v+IX) | SET 7,(v+IX) LD C,(v+IX) | SET 7,(v+IX) LD D,(v+IX) | SET 7,(v+IX) LD E,(v+IX) | SET 7,(v+IX) LD H,(v+IX) | SET 7,(v+IX) LD L,(v+IX) | SET 7, (v+IX) | SET 7,(v+IX) LD A,(v+IX)

Note: These opcodes have a byte between the third and fourth bytes to specify the value (v).

### (***) Opcodes extended on two-byte which begin with EDh

ED | 00 | 01 | 02 | 03 | 04 | 05 | 06 | 07 | 08 | 09 | 0A | 0B | 0C | 0D | 0E | 0F

00

10

20

30

40 | IN B,(C) | OUT (C),B | SBC HL,BC | LD (ad),BC | NEG | RETN | IM 0 | LD i,A | IN C,(C) | OUT (C),C | ADC HL,BC | LD BC,(ad) | NEG | RETI | IM 0 | LD R,A
50 | IN D,(C) | OUT (C),D | SBC DE,BC | LD (ad),DE | NEG | RETN | IM 1 | LD A,i | IN E,(C) | OUT (C),E | ADC HL,DE | LD DE,(ad) | NEG | RETI | IM 2 | LD A,R
60 | IN H,(C) | OUT (C),H | SBC HL,HL | LD (ad),HL | NEG | RETN | IM 0 | RRD | IN L,(C) | OUT (C),L | ADC HL,HL | LD HL,(ad) | NEG | RETI | IM 0 | RLD
70 | IN (C) | OUT (C),0 | SBC HL,SP | LD (ad),SP | NEG | RETN | IM 1 | NOP | IN A,(C) | OUT (C),A | ADC HL,SP | LD SP,(ad) | NEG | RETI | IM 2 | LD R,R

80

90

A0 | LDI | CPI | INI | OUTI | | | | | LDD | CPD | IND | OUTD
B0 | LDIR | CPIR | INIR | OTIR | | | | | LDDR | CPDR | INDR | OUTR
C0 | | MULUB A,B | | MULUW HL,BC | | | | | | MULUB A,C
D0 | | MULUB A,D | | MULUW HL,DE | | | | | | MULUB A,E
E0 | | MULUB A,H | | MULUW HL,HL | | | | | | MULUB A,L
F0 | | MULUB A,(HL) | | MULUW HL,SP | | | | | | MULUB A,A

Note: Some of these opcodes are followed by two bytes to specify an address (ad).

### (****) Opcodes extended on two or three byte which begin with FDh (register IY)

See the tables of extended opcodes which begin with DDh and DDh+CBh. Replace DDh by FDh to obtain the code of statements for register IY.

### Description of colors

- The green statements refer to inputs/outputs.
- The purple statements concern interruptions.
- The statements in red are undocumented by Zilog for the Z80. Some Z80-compatible CPUs do not have all of these statements.
- The statements in sky blue are unsigned multiplications. These are specific statements for the R800 (MSX turbo R). MULUB multiplies the two indicated 8-bit registers and sets the result in HL. MULUW multiplies both 16-bit registers and sets the result in HL (MSB) and DE (LSB). Barred statements are not guarantees of operation.

### About Undocumented Statements (in red)

- Undocumented statements are rarely used in MSX programs.
- The statement SLL of opcodes CBh 30h ~ CBh 37h (in dark red) has been replaced on R800 by SLA (same as CBh 20h ~ CBh 27h).
- On Z80 the undocumented opcodes which begin with DDh CBh or FDh CBh correspond to the execution of the two statements indicated in the cell at same time.
- Empty cells correspond to a NOP whose execution takes 8T states and increment by two the register R. Same for the mirrors of NEG, RETN and IM (in italic and darker red). Same also for opcodes which begin with DDh CBh and FDH CBh.
- All statements for the registers IXH, IXL, IYH and IYL are official statements on R800.

### (List v1.10 by GDX)

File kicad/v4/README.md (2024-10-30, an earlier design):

# Revision 4 Prototype

Although Fourth Revision is a prototype, it works with both MSX Hotbit (with 512KB mapper) and MSX Expert. The third revision has not been pulled because it didn't work.

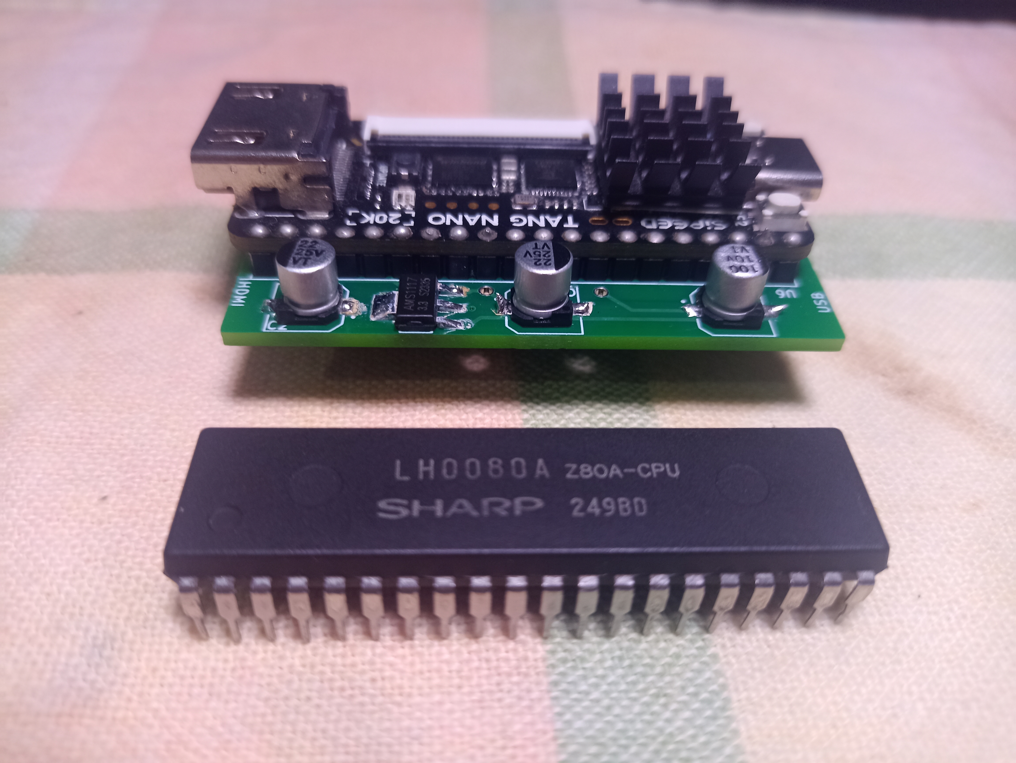
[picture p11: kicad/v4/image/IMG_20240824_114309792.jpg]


## BOM

Check our [Interactive BOM](https://html-preview.github.io/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) to have better details.

| Reference | Chip | Value |
|:-----:|:-----:|:-----:|
| U1~U2 | 74HCT373 (TSSOP-20) | - |
| U3~U4 | 74LVT245 (TSSOP-20) | - |
| U5 | 74LVC245 (TSSOP-20) | - |
| U6 | Tang Nano 20k | - |
| U7 * | AMS1117-3.3 (SOT-223) | - |
| D1* | 1N5817 (THT) | - |
| D2* | DSS32 (SOD123FL) | - |
| C1 | 16V SMD Capacitor | $\mathsf{100\ \mu F}$ |
| C2~C3 ** | 16V SMD Capacitor | $\mathsf{22\ \mu F}$ |
| R1 | Resistor (0603) | $\mathsf{10\ k\Omega}$ |

\* Choose D1 or D2 to use if you want voltage protection over HDMI. You can also choose not to use them by placing a jumper, but make sure to power MSX before connecting Goa'uld to an HDMI monitor.

\*\* These are also optional if you want to use Tang Nano 20k internal voltage regulator. If so, make sure to close J3 and J4 Jumpers.

## Jumper Setup

The recommended jumper configuration set is with 3.3V voltage regulator setup:

|Jumper | State |
|:-----:|:-----:|
| J1 | Z80 Header |
| J2 | Closed (solder) |
| J3 | Open |
| J4 | Open |

If you want to use with internal Tang Nano 20K regulator:

|Jumper | State |
|:-----:|:-----:|
| J1 | Z80 Header |
| J2 | Closed (solder) |
| J3 | Closed (solder) |
| J4 | Closed (solder) |

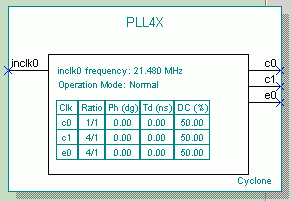
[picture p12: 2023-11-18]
fpga/OCM_3.9/sys/pll4x.gif

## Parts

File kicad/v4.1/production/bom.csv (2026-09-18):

Designator | Footprint | Quantity | Value | LCSC Part #
C4, C5, C6, C7, C8 | 0603 | 5 | 100nF | C1591
D1 | schottky | 1 | DSS32_SOD123FL | C55137670
J1 | Z80 | 1 | Z80CPU
J2 | UART_EXPANSION | 1 | ~
J3 | TN20K | 1 | Tang Nano 20k
PROG/RUN | SolderJumper-2_P1.3mm_Open_TrianglePad1.0x1.5mm | 1 | ~
R1 | 0603 | 1 | 10k | C191124
R2, R3 | 4x0603_Concave | 2 | 16k | C1739401
U1, U2 | TSSOP-20 | 2 | 74HCT373 | C240801
U3, U4 | TSSOP-20 | 2 | 74LVC245 | C7848
U5 | TSSOP-20 | 1 | 74HC245 | C37101

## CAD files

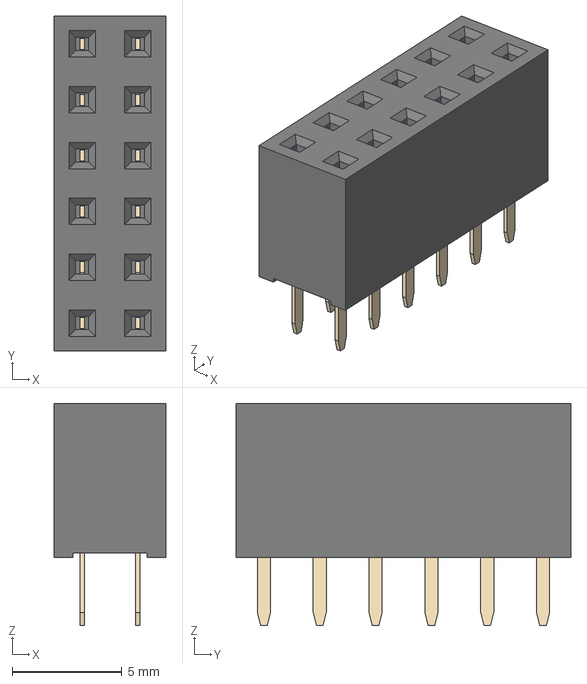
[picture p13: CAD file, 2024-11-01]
kicad/v1_smd/librerias/3D/PinSocket_2x06_P2.54mm_Vertical.step
5.08 x 15.2 x 10.1 mm

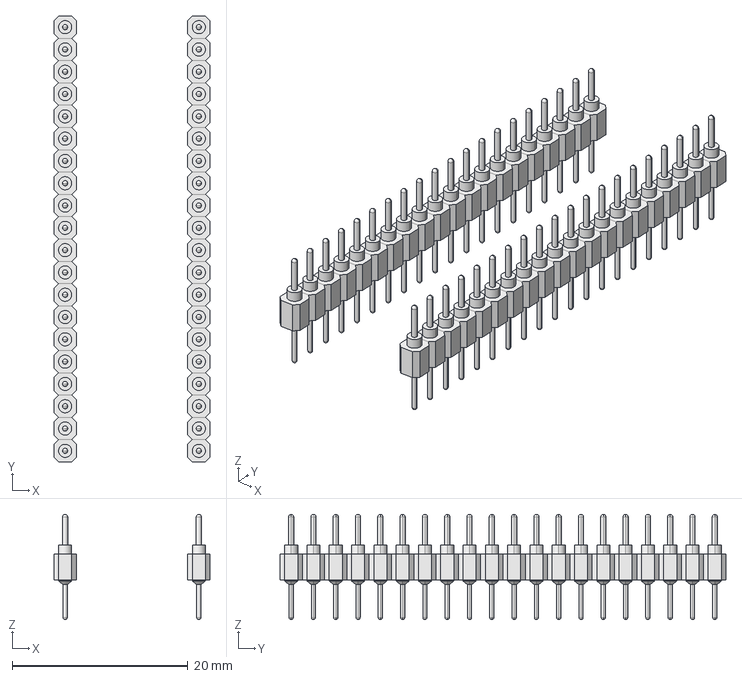
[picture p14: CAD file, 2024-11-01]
kicad/v1_smd/librerias/3D/Z80_PINHEADER.step
17.8 x 50.8 x 12.0 mm
Header-Male-round x 40

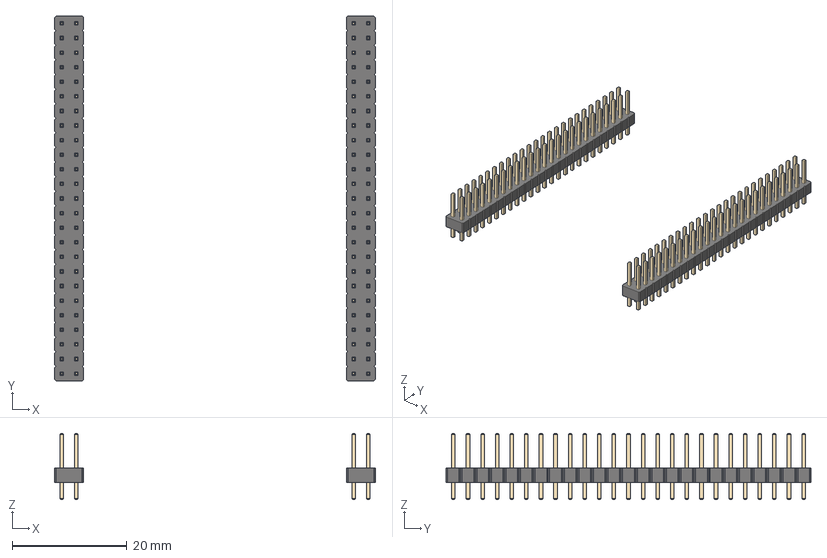
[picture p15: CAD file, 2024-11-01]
kicad/v1_smd/librerias/3D/Qmtech_xc7a15t_35t.step
55.9 x 63.5 x 11.5 mm
PinHeader_2x25_P254mm_Vertical x 2

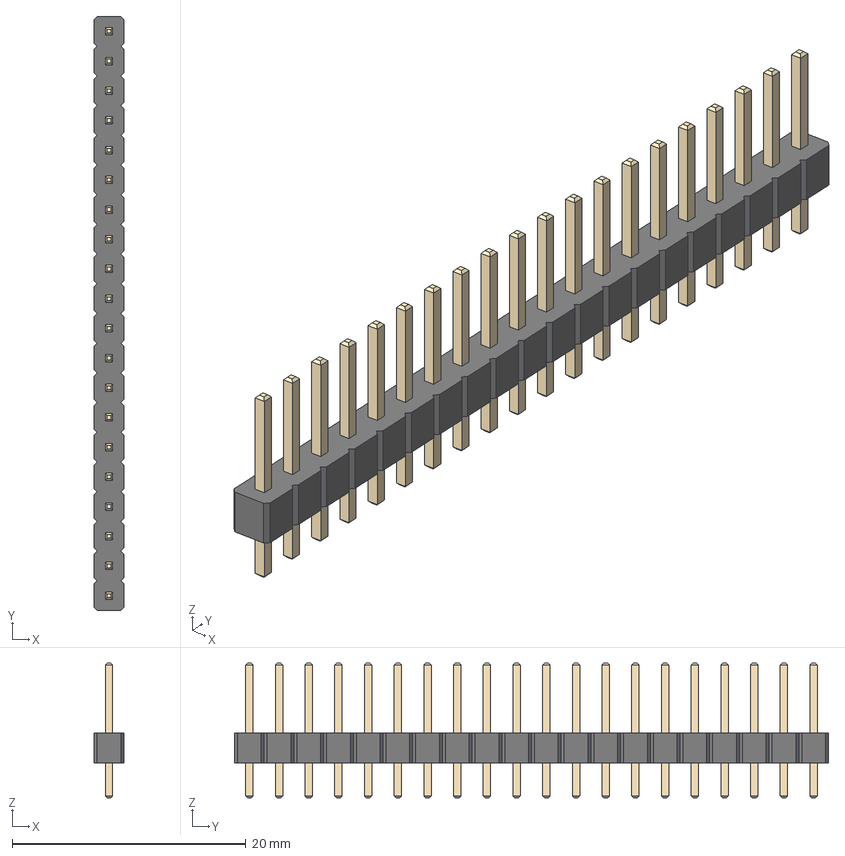
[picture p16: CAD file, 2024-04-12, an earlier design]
kicad/v2/librerias/3D/PinHeader_1x20_P2.54mm_Vertical.step
2.54 x 50.8 x 11.5 mm

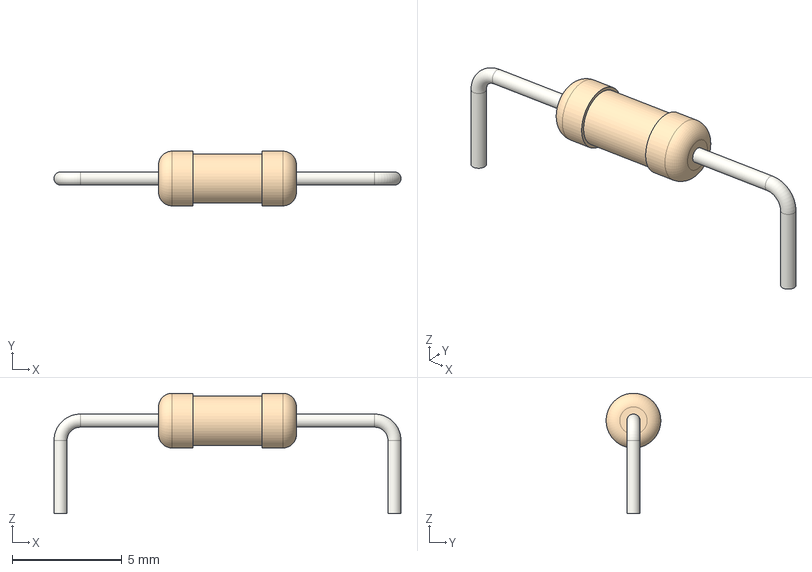
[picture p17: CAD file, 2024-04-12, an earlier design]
kicad/v2/librerias/3D/R_Axial_DIN0207_L6.3mm_D2.5mm_P15.24mm_Horizontal.step
15.8 x 2.50 x 5.50 mm

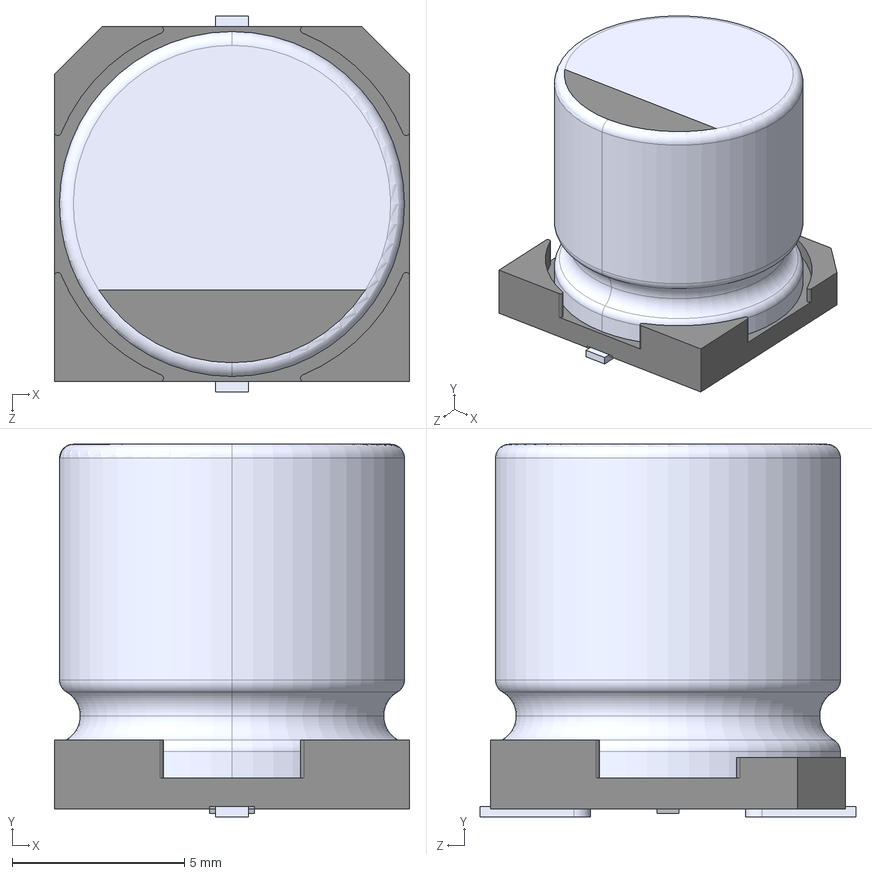
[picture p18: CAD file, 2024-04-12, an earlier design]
kicad/v2/librerias/3D/CAP.STEP
10.3 x 10.8 x 10.9 mm

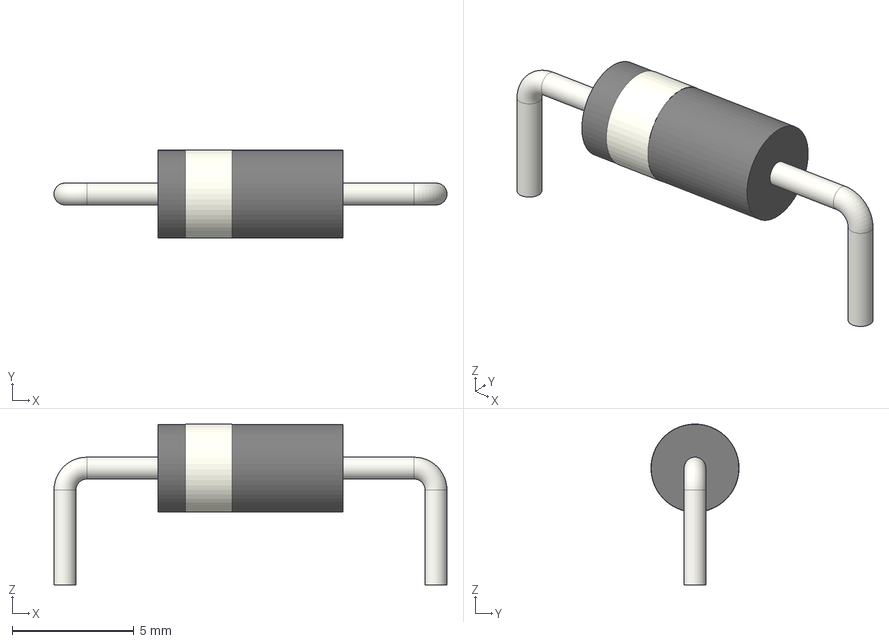
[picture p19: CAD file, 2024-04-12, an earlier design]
kicad/v2/librerias/3D/D_DO-15_P15.24mm_Horizontal.step
16.1 x 3.62 x 6.61 mm

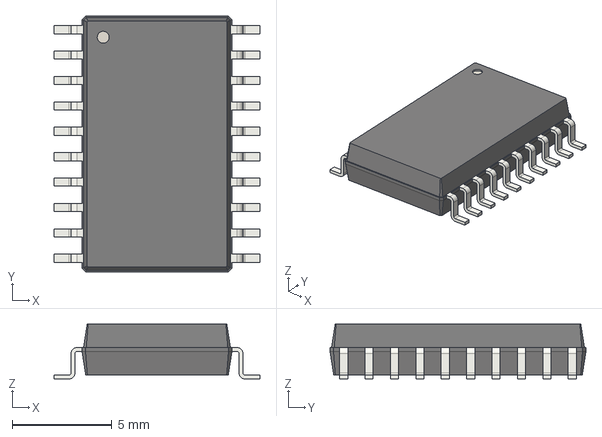
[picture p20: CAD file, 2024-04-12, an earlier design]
kicad/v2/librerias/3D/SOIC-20W_7.5x12.8mm_P1.27mm.step
10.3 x 12.8 x 2.75 mm

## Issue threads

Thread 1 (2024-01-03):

BOM details

windship, 2024-01-03:
Hello, thank you for nice project.

Can you kindly share BOM or components detail for this board? Thanks!

jabadiagm, 2024-01-05:
Hi, thank you!

You can find the components in the kicad schematics. Please mind that some users are having troubles with the board, it looks like new tang 20k are somewhat different to the ones made one year ago.

Good day.

Enviado desde mi Alcatel OT511

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

windship, 2024-01-05:
Oh okay. I found BOM data from KiCAD file. Thank you for kind reply!

By the way, can you tell me more about the troubles they had please?
 - What happened exactly?
 - How can I recognize new and old TN20k?
 - Can you solve it in next update?

jabadiagm, 2024-01-05:
Hi,

> What happened exactly?
Corruption in data or address bus after a few cycles or minutes
> How can I recognize new and old TN20k?
Couldn’t tell, externally are the same
> Can you solve it in next update?
I’be been unable to replicate problem with my tangs, so I suggest waiting for a new version with different fpga.

Enviado desde mi Alcatel OT511

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

windship, 2024-01-05:
Hmm okay I see. So do you have a plan to make a new version of this board with different fpga? If so, can you tell me the estimated date?
And let me know this more clearly: Which version of TN20K is proper with your board? Old or new one?

jabadiagm, 2024-11-01:
Hi,  there is new board version which solves biggest compatibility issues, no need to replace tang.

Closed 2025-01-08.

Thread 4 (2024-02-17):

About the version of the Tang Nano 20k

YouInSun, 2024-02-17:
Could you let me know the version of Tang Nano 20k?
example : please look at the captured picture.

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

jabadiagm, 2024-02-17:
Hi!

all my tangs are v3921 and yet they behave differently with some .fs’s, it would be nice to know why.

Enviado desde mi Alcatel OT511

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

YouInSun, 2024-02-17:
Hi,
Thank you for your quick reply.
If I flash the 01_Z80_V9958_goauld.fs, should I use the version 0.6 of Sombrero_MSX_Goa'uld.pdf ?

Regards.

jabadiagm, 2024-02-17:
Hello,

firmware works the same with both hardware versions, 0.6 removes two unused signals which caused overheating in U4 when Vcc is much bigger than 5V.

Enviado desde mi Alcatel OT511

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

YouInSun, 2024-02-18:
Hello,

I've got the successful operating by your work!
Thank you very much!.

Best Regards.

jabadiagm, 2024-02-18:
Great news! Thank you for you feedback.

Enviado desde mi Alcatel OT511

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

Closed 2024-02-18.

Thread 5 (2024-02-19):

About the remained RAM size

YouInSun, 2024-02-19:
Hello,
I applied your solution with GoldStar FC-200 and the remained memory shows about 12Kbytes even the original machine gets 24Kbytes.
Could you let me know any possibility shows the size?
Note: I programmed the No. 5 option which has all options(bios sound and mapper)

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

Thank you for your reply in advance.

jabadiagm, 2024-02-19:
Hi,

I’m sorry, this means firmware is not stable in your tang, different tangs behave differently, still don’t know the reason why.

Until a fix is found, please try a version without mapper (01, 02, 03).

Enviado desde mi Alcatel OT511

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

YouInSun, 2024-02-19:
Hi,

Thank you for your response however I've got a hint to restore remained memory.
When I connected 5v power to the Tang Nano's USB-c port, I've got increased memory. (about 28KBytes)
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

For your information!
Regards.

YouInSun, 2024-02-21:
However, If 4MB mapper is correct, my understanding is that the remained memory would not be 28KB...

jabadiagm, 2024-02-21:
Hi,

that’s correct. The thing is, Basic can only deal with 28815 bytes maximum, even with a 4 MB mapper. To check total memory, use a tool like testram in MSX-DOS:

https://msxhub.com/TESTRAM

Enviado desde mi Alcatel OT511

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

YouInSun, 2024-02-25:
Thank you for your explanation!
I will check the tool if I have MSX-DOS.

Regards.

Closed 2024-02-25.

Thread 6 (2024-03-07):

Cannot Flash bitstream

Chandler-Kluser, 2024-03-07:
I can`t flash bitstream in impl/pnr using Gowin EDA Programmer and also openFPGALoader.

Using Official EDA, the tool says the Gowin device was not found.

Using openFPGALoader, this is the output I get:

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

Is there any programming step I missed?

BTW, thanks for the great job!!

Chandler-Kluser, 2024-03-07:
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

my tang nano 20k is v3921 and it can be successfully flashed with other .fs files

Chandler-Kluser, 2024-03-08:
Could get it to flash with commit fe25ad2720eea09d6686d502b8feddcb6055501d, before v0.61

jabadiagm, 2024-03-08:
Hi!

This is really strange, all .fs are created with same ide version, win64 1.9.9 beta 4, and tried on my tangs. Now that you flashed a previous version, if you try to flash the last one does it fail again?

Thank you for your feedback

Enviado desde mi Alcatel OT511

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

Chandler-Kluser, 2024-03-08:
I have not tried, but I can check it!

For now I am more concerned about not getting video output from my board 😅

jabadiagm, 2024-03-09:
That’s bad, hdmi output should always be on. If you get hdmi signal with black screen it’s either a problem with multiplexer (hct373’s) or unstable firmware.

Enviado desde mi Alcatel OT511

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

Chandler-Kluser, 2024-03-09:
I believe it is something with the power, when I connect the board into the socket the leds gets lit

Chandler-Kluser, 2024-03-12:
> Now that you flashed a previous version, if you try to flash the last one does it fail again?

It failed, and worse... even that commit is not flashing anymore and I believe I have bricked the board bootloader somehow, because the last time I have tried I have got a lot of sse errors

I will try to get it back to work, although I have another board with me here.

Besides, is there any debug info to help troubleshooting?

jabadiagm, 2024-03-12:
Usb plug in tang is in the cheap side (tn9k specially) I have a couple boards difficult to flash, maybe this is similar and your firmware got corrupted during flashing due to bad contact. To prevent firmware from loading, press s1 button, connect usb cable and try to flash a simple firmware like the leds demo (keep s1 pressed during whole process).  Once reflashed, jtag pins will be back and board will be responsive, hopefully.

Enviado desde mi Alcatel OT511

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

Chandler-Kluser, 2024-03-13:
> To prevent firmware from loading, press s1 button, connect usb cable and try to flash a simple firmware like the leds demo (keep s1 pressed during whole process).

I have just saved my tang nano 20k :smile:

I have got a black screen by using the 01_Z80_V9958_goauld.fs, is it expected? :sweat_smile:

jabadiagm, 2024-03-14:
Unfortunately, it is both common and bad sign. If hardware is ok and you have hdmi signal but black screen, the firmware is running but unstable. Still don’t know the reason, some tangs work and some fail. I’m trying a different fpga vendor to tell wether it’s a software or a hardware problem.
In the meantime, you may try different firmwares and, even better, different tangs.

Enviado desde mi Alcatel OT511

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

Chandler-Kluser, 2024-03-14:
I have tried with another tang nano 20k and I noticed a diferent pattern of leds, I will order another board and brand new ICs

jabadiagm, 2024-03-18:
Two tangs with black screen is a bit suspicious. Please double check pcb  weldings, sockets and be sure to use 74HCT373, not HC.

Enviado desde mi Alcatel OT511

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

Chandler-Kluser, 2024-03-18:
> be sure to use 74HCT373, not HC

I just have hct with me here, shouldn't they be compatible?

jabadiagm, 2024-03-18:
HC doesnt work with tang because voltage level for logic 1 is 3.3-0.4= 2.9V aprox. and HC requires 3.15 minimum. HCT works nice with 2.9 V.

0.4 V is voltage drop in goauld diode.

Enviado desde mi Alcatel OT511

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

Chandler-Kluser, 2024-03-18:
> HC doesnt work with tang because voltage level for logic 1 is 3.3-0.4= 2.9V aprox. and HC requires 3.15 minimum. HCT works nice with 2.9 V.

you mean this for 74XX245 or for 74XX373 :sweat_smile:

jabadiagm, 2024-03-18:
Problem is 74HCT373. This is the latch for the address bus. Tang outputs are 3.3V and this signal is the input of 74HCT373. HC and HCT are compatible when using 5V, but here we are using 3.3V

To summarize, use this:
U3, U4, U5: 74LVC245
U1-U2: 74HCT373

Enviado desde mi Alcatel OT511

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

Chandler-Kluser, 2024-03-27:
I did some modifications in the design:

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

If you want I can make a PR with the kicad projects with two board revisions I have made, there is nothing special I only changed the IC package.

But there is, actaully, a problem...

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

I was able to make it work with my MSX Sharp Hotbit 1.1, but it only worked in MSX1 mode `01_Z80_V9958_goauld.fs` and with TMS9918 connected...

I was able to play some games in my mapper cartridge, but I could not get to work any 9958 versions with my MSX here, are you able to tell me a tip of what kind of problem it can be?

Also, I could not get v0.61 to flash in neither of my Tang Nano 20k FPGAs, are you sure the bitstream in the last commit can be flashed into the board?

Thanks in advance for your patience and great work!!

Chandler-Kluser, 2024-03-28:
Update: This time I was able to flash 0.61 version to my TN20k, I have built from source and flashed the default bitstream and then it worked (don`t know why that happened).

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

But even using the latest version v9958 is still not working (02, 03, 04 and 05 .fs)

jabadiagm, 2024-03-28:
You new pcb is really cool! This is more like it should be, a pcb with the
size of a Z80.

If one firmware works in your board, that's good news, it means your
hardware is OK and the fails are caused by the different firmwares. Problem
is, if the only working is 01_Z80_V9958_goauld.fs, then you are missing
MSX2 bios, so most of the MSX2 software won't work. Aleste should work, at
least the intro.

Regarding version 0.61, no big problems here. I have the usual problems
working with tk20k: connection drops, instabilities from time to time. Same
as other fpga's. Tang 9k is another story, it's really a pain in the ass. I
have to use usb2 (not blue) ports and a usb hub to flash it. Tip: connect
and disconnect tang using the tang (usb-c) connector, not usb-a connector.

https://www.msx.pics/images/2024/03/28/programando2.png

I have four tangs 20k, two goa'uld pcb's and three MSX for tests: Omega,
Toshiba HX-20 and Sony Hitbit HB-75P. With every new version I try all
combinations and they worked fine. But the fact is, nobody has reported
success with firmwares 04, 05. So, this means that something in my system
must be different and it makes things work. About what could it be, I
haven't got a clue.

https://www.msx.pics/images/2024/03/28/puebas.jpeg

On Thu, Mar 28, 2024 at 4:59 AM Chandler Klüser ***@***.***>
wrote:

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

jabadiagm, 2024-03-28:
I forgot, you mentioned about having TMS9918 connected. That's the way it is, goa'uld board blocks bus requests (IORQ, MREQ)  for external devices (TMS, msx1 bios) when there is an internal device bith bigger priority (V9958, msx2 bios...). That's easy to test: when goa'uld board is in place, you should see no analog video.

Chandler-Kluser, 2024-03-28:
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

Great, so do you want a PR with the new board?

Additionally, how can I make the MSX2+ bios work (the 02 and 03 versions)?

jabadiagm, 2024-03-30:
If the 'R' in PR means Repository, yes, please.

On tang, I'm working on a reduced version with bios & v9958 only. Tangs work better with a low number of logic elements.

jabadiagm, 2024-04-09:
There is a new version, trying to get a low number of logic elements in fpga. Sound and mapper is removed. Hopefully this will work in more devices. As usual, tested in Omega, Toshiba HX-20 and Sony Hitbit HB-75P.

Chandler-Kluser, 2024-04-09:
I can test in my msx hotbit, too

Chandler-Kluser, 2024-04-09:
> I can test in my msx hotbit, too

@jabadiagm black screen with TMS9918 attached in VDP slot

jabadiagm, 2024-04-10:
That's interesting...

Black screen with or without hdmi?
Are all leds lit?

(TMS9118  needs to be always on, without it there is no 3.6 MHZ clock)

Chandler-Kluser, 2024-04-10:
leds blinking, there is HDMI signal

Chandler-Kluser, 2024-04-10:
is there a way to help the development like doing a discord server/telegram channel or something like that?

I believe I can help giving more details, I also made a PR with a new board revision

Chandler-Kluser, 2024-04-10:
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

jabadiagm, 2024-04-10:
That’s a good idea, I have created a telegram group:

https://t.me/+tsXxv2i2q3M4YWFk

Enviado desde mi Alcatel OT511

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

YouInSun, 2024-04-12:
> You new pcb is really cool! This is more like it should be, a pcb with the size of a Z80. If one firmware works in your board, that's good news, it means your hardware is OK and the fails are caused by the different firmwares. Problem is, if the only working is 01_Z80_V9958_goauld.fs, then you are missing MSX2 bios, so most of the MSX2 software won't work. Aleste should work, at least the intro. Regarding version 0.61, no big problems here. I have the usual problems working with tk20k: connection drops, instabilities from time to time. Same as other fpga's. Tang 9k is another story, it's really a pain in the ass. I have to use usb2 (not blue) ports and a usb hub to flash it. Tip: connect and disconnect tang using the tang (usb-c) connector, not usb-a connector. https://www.msx.pics/images/2024/03/28/programando2.png I have four tangs 20k, two goa'uld pcb's and three MSX for tests: Omega, Toshiba HX-20 and Sony Hitbit HB-75P. With every new version I try all combinations and they worked fine. But the fact is, nobody has reported success with firmwares 04, 05. So, this means that something in my system must be different and it makes things work. About what could it be, I haven't got a clue. https://www.msx.pics/images/2024/03/28/puebas.jpeg
> […](#)
> On Thu, Mar 28, 2024 at 4:59 AM Chandler Klüser ***@***.***> wrote: Update: This time I was able to flash 0.61 version to my TN20k, I have built from source and flashed the default bitstream and then it worked (don`t know why that happened). image.png (view on web) <https://github.com/jabadiagm/MSXgoauld_tn20k/assets/29960960/368cf7f9-ce77-4571-b497-d5c99c63b89d> But even using the latest version v9958 is still not working (02, 03, 04 and 05 .fs) — Reply to this email directly, view it on GitHub <[#6 (comment)](https://github.com/jabadiagm/MSXgoauld_tn20k/issues/6#issuecomment-2024352859)>, or unsubscribe <https://github.com/notifications/unsubscribe-auth/ACOYT426VOIJVDIBX5O7YXLY2OIRJAVCNFSM6AAAAABELCABXWVHI2DSMVQWIX3LMV43OSLTON2WKQ3PNVWWK3TUHMZDAMRUGM2TEOBVHE> . You are receiving this because you commented.Message ID: ***@***.***>

Hello,
I can report the 05_Z80_V9958_bios_mapper_sound_goauld.fs of V0.61 is doing well to my FC-80(MSX1). Please look at my capture below. And sound is good!
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

Chandler-Kluser, 2024-04-12:
Thanks for your feedback!!

Regarding the bitstream, we are rolling back some features in order to make the project compatible with more MSX models.

I am testing with Sharp MSX Hotbit and Gradiente MSX Expert, I believe very soon we are going to present news with better compatibility.

@jabadiagm @YouInSun

Closed 2024-04-12.

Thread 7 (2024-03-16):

About /M1, /RFSH, /WAIT operations

YouInSun, 2024-03-16:
Hello,

Thank you for your many help so far and I can see a MSX2+ on my MSX nearly :)
I heard that the most game ROM cartridges don't use specified Z80's control pins.(/M1, /RFSH, /WAIT, etc)
And I think the pins are used by some cartridges which can give and take the signals with Z80 for fetching op code directly.
Could I ask about how I can check whether the pins operate well without a cartridge which can interact Z80 with the pins?
Or, did you checked emulating the pins?

Thank you for your reply in advance.

Best regards.

YouInSun, 2024-03-19:
Hi,

Sorry about my inexperience with the application. What I got signal waveforms were just below.
It might be good to check when I have a device that can interact with the control signals :)
Thank you for your reply anyway.
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

jabadiagm, 2024-03-19:
You need a modified firmware to run GAO, follow these steps:

Enable gao config file in project
[image: imagen.png]
Build firmware
[image: imagen.png]

Flash new firmware, keep in mind the right name is ao_0.fs
[image: imagen.png]
Start GAO

[image: imagen.png]

Select FT2CH cable
[image: imagen.png]

Start capturing
[image: imagen.png]
Power MSX on

[image: imagen.png]

Start sequence should be captured,

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

YouInSun, 2024-03-23:
Hi,

Thank you for your kind explanation and I got a timing chart like below.
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
However, could you let me know how I can trigger /WAIT signal on my MSX?

Best regards.

YouInSun, 2024-03-23:
Hi,

I've got it another time!
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

jabadiagm, 2024-03-23:
Hi,

your second capture looks nice. There should be a pulse in WAIT right after a pulse in M1. First capture had something wrong, maybe a loose contact.

There is an explanation about WAIT signal in MSX here:

https://www.msx.org/forum/msx-talk/development/extra-wait-signal-all-instructions

Enviado desde mi Alcatel OT511

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

YouInSun, 2024-04-12:
Thank you for your help!.

Best Regards.

Closed 2024-04-12.

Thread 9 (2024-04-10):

Don't see how this can get 3.2v stable.

zambujal, 2024-04-10:
Not exact an issue just a question... how this regulates the 3.2v, from the resistor I guess... but I don't see the circuit in series with this, maybe I am totaly wrong.

jabadiagm, 2024-04-12:
Hi, tang has an internal regulator, it takes 5V from the msx and provides 3.3V for the 74hct/74lvc

Enviado desde mi Alcatel OT511

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

zambujal, 2024-04-12:
ha... nice indeed.

zambujal, 2024-04-12:
I will test this on 2 different MSX panasonic and philips...

zambujal, 2024-04-13:
I made the smaller IC's version but I noticed there was no condensators. I put them and redraw the traces, took me 5 minutes though. hope it will work. :D I have 2 MSX philips msx1 the most common here in europe and the panasonic F1-A1 msx2.

Closed 2025-01-08.

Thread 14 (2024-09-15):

Missing decoupling capacitors

adailtonjn68, 2024-09-15:
All the power pins should have decoupling capacitor. Their lack may cause instability.
I have seen this in many designs where the board used to restart itself. The issue is solve by using decoupling capacitors very close to the power pins.
It is nice to use them also in the voltage regulator.

I counted at least 15 places you should have decoupling capacitors.
A good value is 100 nF.

adailtonjn68, 2024-09-17:
Perfect.
Very nice work. Good luck

jabadiagm, 2025-01-08:
All workng boards are including decoupling capacitors now

Closed 2025-01-08.

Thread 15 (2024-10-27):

Supply voltage out of recommended specs for 74LVC245 on Rev4

herraa1, 2024-10-27:
In the published schematic for V4 the supplied voltage for U5 (74LVC245) is 4.7V (5V) and that exceeds the recommended supply voltage range of 1.65V-3.6V as specified in page 5 (section 7.3) of the [SN74LVC245A datasheet](https://www.ti.com/lit/ds/symlink/sn74lvc245a.pdf) by Texas Instruments.

herraa1, 2024-10-29:
Thanks. Looking forward to the new board revision.
Maybe a short errata could be added to the readme to discourage people from building the rev4 board as it is known to be flawed.

herraa1, 2024-10-29:
I've created PR #16 to add the short errata for rev4.

stefanobaldo, 2024-11-30:
Apologies for reopening this topic, but I’ve ordered some Rev4 boards without noticing the errata. Would replacing the 74LVC245 with the 74HC245 be a possible solution, given that I’ve already ordered the PCBs?

stefanobaldo, 2024-12-01:
@jabadiagm, any chance you could help me out with this?

jabadiagm, 2024-12-04:
Sure, if you have an outdated pcb, follow the steps in section "Update from previous hardware":

Replace U1, U2 -> 74HC373, U5 -> 74HC245
Solder a 10K resistor array to data bus lines, pulled up to 5V

Chandler-Kluser, 2024-12-15:
> Apologies for reopening this topic, but I’ve ordered some Rev4 boards without noticing the errata. Would replacing the 74LVC245 with the 74HC245 be a possible solution, given that I’ve already ordered the PCBs?

There is no problem about using 74LVC245 since they are 5V tolerant. Although it is known this voltage is not recommended by manufactors, in most datasheets you will be able to find that.

I also have made several boards with 74LVC245 with no issues, they are not waste.

herraa1, 2024-12-15:
The problem is not the input tolerance. The problem is powering them with 5v.

On Sunday, December 15, 2024, 9:04 AM, Chandler Klüser ***@***.***> wrote:

Apologies for reopening this topic, but I’ve ordered some Rev4 boards without noticing the errata. Would replacing the 74LVC245 with the 74HC245 be a possible solution, given that I’ve already ordered the PCBs?

There is no problem about using 74LVC245 since they are 5V tolerant. Although it is known this voltage is not recommended by manufactors, in most datasheets you will be able to find that.

I also have made several boards with 74LVC245 with no issues, they are not waste.

—
Reply to this email directly, view it on GitHub, or unsubscribe.
You are receiving this because you modified the open/close state.Message ID: ***@***.***>

Chandler-Kluser, 2024-12-15:
Could you, please, read one more time what I have written?

> The problem is not the input tolerance. The problem is powering them with 5v. On Sunday, December 15, 2024, 9:04 AM, Chandler Klüser ***@***.***> wrote: Apologies for reopening this topic, but I’ve ordered some Rev4 boards without noticing the errata. Would replacing the 74LVC245 with the 74HC245 be a possible solution, given that I’ve already ordered the PCBs? There is no problem about using 74LVC245 since they are 5V tolerant. Although it is known this voltage is not recommended by manufactors, in most datasheets you will be able to find that. I also have made several boards with 74LVC245 with no issues, they are not waste. — Reply to this email directly, view it on GitHub, or unsubscribe. You are receiving this because you modified the open/close state.Message ID: ***@***.***>

Chandler-Kluser, 2024-12-15:
@stefanobaldo não há necessidade de comprar outros componentes, se você tiver interesse eu tenho componentes e placas à disposição. Se precisar, pode entrar em contato.

Se você já tiver os 74HC245 à sua disposição, você pode usá-los. Os resistores de 10k são recomendados, mas opcionais.

==========================================================================

@stefanobaldo there is no need to buy other components, if you are interested I have components and boards available. If you need them, you can contact me.

If you already have the 74HC245 at your disposal, you can use them. The 10k resistors are recommended, but optional.

herraa1, 2024-12-15:
I read the following:

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

The OP uses a board that feeds 5V into VCC of U5 which is a 74LVC245 in his revision.

The datasheet of the 74LVC245 clearly states that the recommended VCC is max 3.6V for operating conditions.

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

The datasheet also informs about the absolute maximum ratings, which in the case of VCC is 6.5V.

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

You seem to imply that there is no problem in using the 74LVC245 out of the recommended values.
I just wanted to make clear that feeding 5V to VCC of the 74LVC245 is out of the recommended operating conditions as specified in the datasheet provided by the manufacturer. And there is no need to power those chips from 5V specially if you have 3V3 around.

[Absolute maximum ratings vs Recommended operating conditions](https://toshiba.semicon-storage.com/ap-en/semiconductor/knowledge/faq/motor-driver-ics/what-are-the-differences-between-the-absolute-maximum-ratings-and-the-recommen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)

Of course, you are free to shoot you in your feet.

Chandler-Kluser, 2024-12-15:
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

The readme has already been updated with useful, sober and polite technical information.

Behaving this way, you can save your comments in your own fork as well as your own board designs.

herraa1, 2024-12-15:
Woa. I though we were into a more open and constructive conversation.

By the way, I want to say that (not being a native english speaker) I used the expression "shoot you in your feet" figuratively (as in causing you trouble yourself in your goals, like in the [Collins definition](https://www.collinsdictionary.com/dictionary/english/shoot-yourself-in-the-foot)). If this was not understood that way, I want to apologize in advance.

If you believe my arguments are not correct (which may be, we are humans and make mistakes) I would have expected you to point to the flaws in my argumentation so we can all learn from each other.

That said, there's no point in wasting each other's time if that's not the case.

Closed 2024-10-29.

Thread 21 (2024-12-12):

Bug into Toshiba HX-20

Papipapito, 2024-12-12:
Hi, I'm testing a unit with various MSX1 and MSX2 and I've noticed that with a Toshiba HX-20 there are many crashes, especially when you use a cartridge, for example Salamander

I don't have this problem with a HX-10 and a VG8235, everything works.

I think it's a memory slot map problem on the HX-20, there's part of the ram in slot 0

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

https://www.msx.org/wiki/Category:Toshiba_HX-20

Is there any way via the Google firmware to avoid this?

jabadiagm, 2024-12-13:
Hi, this is strange, I also use a toshiba hx-20, this model has a not-so-good timing, but should work fine with all firmwares. Slot map should'n be a problem here, goa'uld disables physical slot 0.

First of all, check your chips are:
U1, U2 -> 74HC373, U5 -> 74HC245

In the case it is a timing issue, try with version 0.75, this is the most stable:

https://github.com/jabadiagm/MSXgoauld_tn20k/blob/fdcb691feafe06b07b512ac16160cd4677a6af95/fpga/impl/pnr/Z80_goauld.fs

If timing is the problem, you should see better stability. If stays the same, look for bad contacts in your hx-20: z80 socket, slots... Also, check your voltage is > 5 V

jabadiagm, 2024-12-13:
Another question: Is there a difference if you lift the keyboard? This model is specially tight for goa'uld and temperature may have an effect.

Papipapito, 2024-12-22:
Hello, after some tests I tell you:

The Gould has a 74LVC245 SMD chip and have the arrays connected

I have verified with version 76 and 78 ((current one that works well on VG8235)

On an 8235 that wouldn't start, without the BIOS, everything works perfectly, 99% of games and programs verified

The Toshiba HX 20 is a Japanese version, 100% functional, with z80,  Salamander and other cartiches works perfectly, I have verified it with 2 HX-20 that I have, identical Japanese ones, and the same thing happens.

I attach photos of the Gould and what happens with image corruption of Salamander, With other MSX cartridges, sometimes they start, sometimes they don't start and show basic

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

Even with the MSXpico, tested with this same goauld, nothing starts correctly, and in the 8235, everything works

So after trying 2 HX-20 the goauld in another MSX and different cartridges, I think it is the Toshiba

Now I have it pending next week to test it in a Japanese HX-10 and a Japanese HX-34

And then try it in a National CF3000

Regards

jabadiagm, 2024-12-22:
Hi,

If it fails on 3 HX-20 we can rule out dirty contacts and similar. I bet it has to do with slow buffers. Most MSX use buffers to ensure good voltage and current levels on all chips and slots. Tang brings it own buffers (slow), so the combined delay can be too high.

My HX-20 is european, maybe that's why it works.

You may replace these IC's (no guarantee of success but faster):
U1, U2 -> 74LVC373/74ABT373
U5 -> 74LVC245/74ABT245

Mind that LVC chips powered at 4.7V are outside recommended voltage, but still valid, and no overheat. ABT's are faster, but more sensible to electrical noises.

Papipapito, 2024-12-22:
Hello

Thanks for the reply, so it could be something related to hardware, not software, with the 74xxx. What I'll do is mount a new board for the HX-20 and leave this one that works on the 8235

I thought it could be something related to software with the HX20 BIOS, since I had to remove it on the 8235 because it hung halfway when starting up

What I had in mind as a plan D was to unsolder the two BIOSes and check if it did the same.

Regards

jabadiagm, 2024-12-23:
HX-20's firmware in slot 3-3 is working ok with MSX2+, so no need to remove chip.
On the other way, VG8235 is probably hanging due to MSX2 subrom in Slot 3-0, not compatible with MSX2+
Goa'uld was designed with MSX1 in mind.

jeroentaverne, 2024-12-31:
Regarding the 3.3 volts -> 4.7 volt level translation: did you consider 74HCT in stead of 74HC? 74HCT can work properly with 3.3 volt inputs.

jabadiagm, 2024-12-31:
Hi,

First version of goa’uld had 74HCT for U1, U2. But tang pins have noises coming from the inner logic that lead to corruption in address bus from time to time. If you have an old tang, you will see the big led lighting randomly on boot, that’s the same issue. 74HC have better immunity to noises.

Enviado desde mi Alcatel OT511

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

Papipapito, 2025-01-05:
> HX-20's firmware in slot 3-3 is working ok with MSX2+, so no need to remove chip.
> On the other way, VG8235 is probably hanging due to MSX2 subrom in Slot 3-0, not compatible with MSX2+
> Goa'uld was designed with MSX1 in mind.

I explained myself badly, the 8235 had problems before the goauld, but since I installed it, it works perfectly, removing the bios, since it was stuck looking for the disk drive (blue screen on screen 1)

jeroentaverne, 2025-01-05:
Are the 74LVC373 running at 4.5 volts? That is out of  specifications I guess. Could you modify the PCB so they run at 3.3 volts and try if the system still works?

jeroentaverne, 2025-01-05:
74ABT chips are also a possibility.
Also check my Discord channel with some design discussions if you want to: https://discord.gg/WaHtmesGtp

Papipapito, 2025-01-07:
For more information, with the ABT373 the HX-20 works perfectly with the 1.4 non-smd

jabadiagm, 2025-01-08:
@Papipapito Those are great news!
What made the difference, fw version 0.8, fast buffers or both?

@jeroentaverne: Yes, U1, U2 are running at 4.5 V. This is out of recommended voltage but below maximum allowed value, see:
https://github.com/jabadiagm/MSXgoauld_tn20k/issues/15

Board output chips are 74HC, if voltage is reduced to 3.3V speed will be lower. Tried 74ABT chips and got some freeze/hang from time to time.

jabadiagm, 2025-01-08:
closed as fixed

Closed 2025-01-08.

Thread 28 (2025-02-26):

BOM for 4.1

steswart, 2025-02-26:
Please add the BOM for board 4.1. I.e r2 and r3 as well as x1. Maybe just the differences with board 4.0

steswart, 2025-02-28:
I figured it out by looking at all the kicad file pdf's.

steswart, 2025-02-28:
I figured it out by looking at all the kicad file pdf's.

Closed 2025-02-28.

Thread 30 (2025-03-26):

BOM for the 4.1 smd  board

capsule5000, 2025-03-26:
Greetings and congratulations on the project. I'd like to build it, but I don't see where the component list for the 4.1 SMD board is. I even see a component called X1, which I think is a crystal. Would you be kind enough to provide the component list? Best regards, and thank you.

jabadiagm, 2025-03-28:
Hi capsule, thank you!

You can use same bom for 1.4 smd and 4.1:

```
1	MBR130T1G	Diodo:rectificador de barrera Schottky	C82461
2	YC164-JR-0710K	Rejilla de resistores			C107374
2	74HC373PW.118	IC:digital;latch transparente		C132998
2	SN74LVC245APWR	IC:digital;bus transceiver		C7848
1	SN74HC245PWR	C:digital;bus transceiver		C37101
6	0805B104K500CT	Condensador:cerámico;100nF;50V		C49678
2			Female header 20p 2.54, low profile	Aliexpress
1			Male header 40p 2.54, turned		Aliexpress
```

Board 4.1 has also some pads for a clock generator, used by some MSX with no TMS9918

capsule5000, 2025-04-10:
Thank you very much for your response. One last question: I looked at the version 4 BOM list to find out the IC locations, and I see that there's a different one compared to version 4.1. It's the IC 74LVT245 (ver4) and IC SN74HC245PWR (ver4.1). Are they compatible?
Would:
U1-U2 be 74HCT373,
U3-U4 SN74HC245PWR,
and U5 SN74LVC245APWR? Is that correct?
And finally, I understand that the clock generator doesn't need to be installed, nor does J4. But if it had to be used, based on what you mentioned about some MSX devices requiring it, what clock generator value should I use?
Best regards, and thank you very much.

jabadiagm, 2025-04-10:
Nope, U3-U4 and U5 are swapped, correct are:
```
U1-U2:  74HCT373PW
U3-U4 : SN74LVC245APWR
U5:     SN74HC245PWR
```
Board v4 is optimized for Brazil MSX (Expert, Hotbit). 74LVT245 is faster, and 74HC245 is more compatible.

Clock frequency is 3.58 MHz

capsule5000, 2025-05-04:
Good afternoon, buddy, one last question. There's a photo in your SMD4.1 board project where you can see a bridge soldered to J3. What's the purpose of J3? And behind the board, next to the clock, is J4. What's the purpose of J4? Regards.

nsinav, 2025-07-31:
Hello! I'm also very excited about this project. I have three questions regarding version 4.1.
1) What is J2? I see it's not soldered in the photos.
2) What resistor do I use on R1? I'm only sure it's 0805.
3) What type of crystal can I use on X1? I only know it must be 3.58MHz.

Thanks!

jabadiagm, 2025-08-03:
Hi!

1.     What is J2? It's a header used to communicate with Goa'uld Guardian Angel Board, see [https://github.com/Chandler-Kluser/msx-goauld-ga](url)
2.     What resistor do I use on R1? All resistors are 10K
3.     What type of crystal can I use on X1? Any common crystal that matches the footprint will do. Just remember to disable any other clock source to avoid shorts. Some oscillators may require an additional capacitor.

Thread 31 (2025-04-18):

VDP required

siriokds, 2025-04-18:
Hi! Nice job. I like projects like yours.

Just a tech question: the original TMS9929/18 is required on the motherboard ? If yes, why (technically speaking).

Thanks a lot,
Saverio

jabadiagm, 2025-04-18:
Hi Saverio, thank you!

Original VDP is required because, in most MSX's, it is responsible for clock generation. TMS works at 10.7 MHz for video generation and includes a clock divider by 3 (10.7 / 3 = 3.57 MHz) . This signal is usually used as clock for Z80 and the rest of logic.

There are a few models with independent clock sources, but in general, if TMS is damaged or not installed, you will still need a clock generator.

siriokds, 2025-04-19:
Oh! Ok, thank you for your answer. So you could "solve" it with a wire from a pin of the Tang Nano directly to the pin 38 of TMS9918 socket. Do you have a different fpga config for TMS9928/29 owners (since the CPU clock isn't generated by the VDP), just to detach the original VDP ?

I'd like to use your project on my Sega SC-3000 computer as well. :)

Thanks.

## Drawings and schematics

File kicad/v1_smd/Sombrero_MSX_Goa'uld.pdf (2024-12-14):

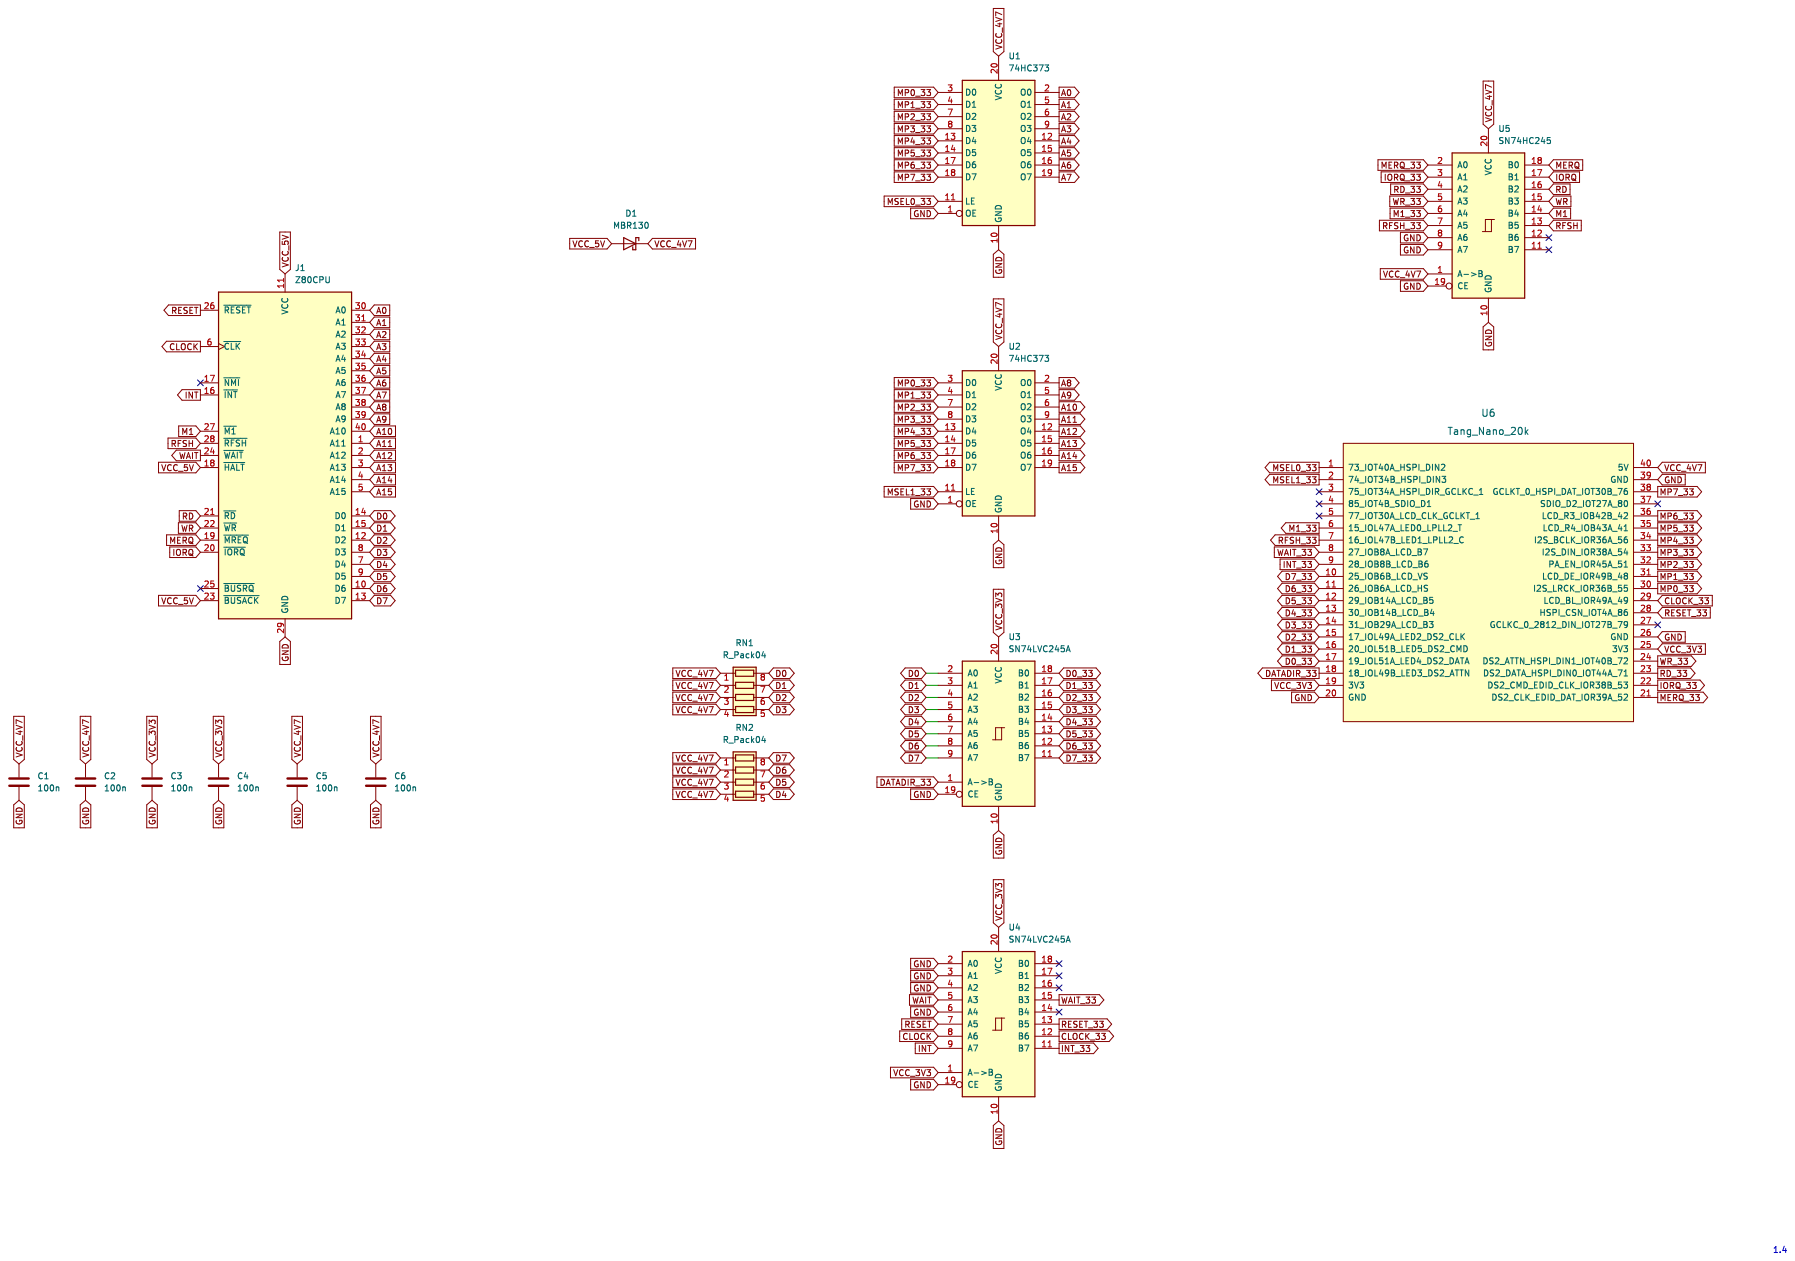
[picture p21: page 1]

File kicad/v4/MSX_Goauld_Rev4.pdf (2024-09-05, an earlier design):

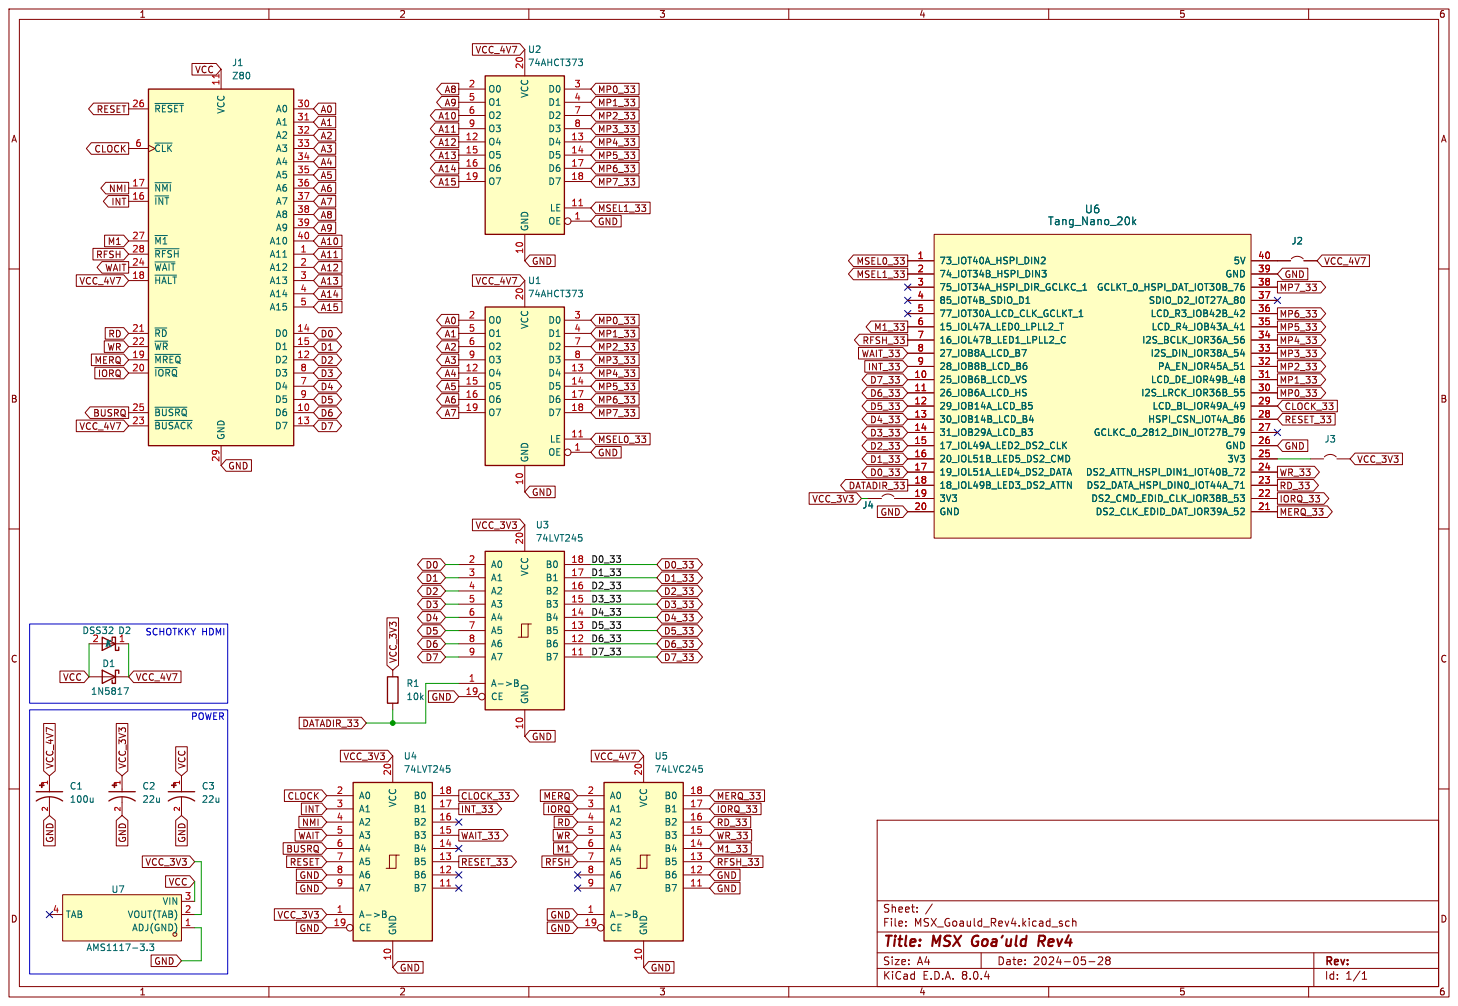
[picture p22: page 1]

File: MSX_Goauld_Rev4.kicad_sch Sheet: /
Id: 1/1 Title: MSX Goa'uld Rev4

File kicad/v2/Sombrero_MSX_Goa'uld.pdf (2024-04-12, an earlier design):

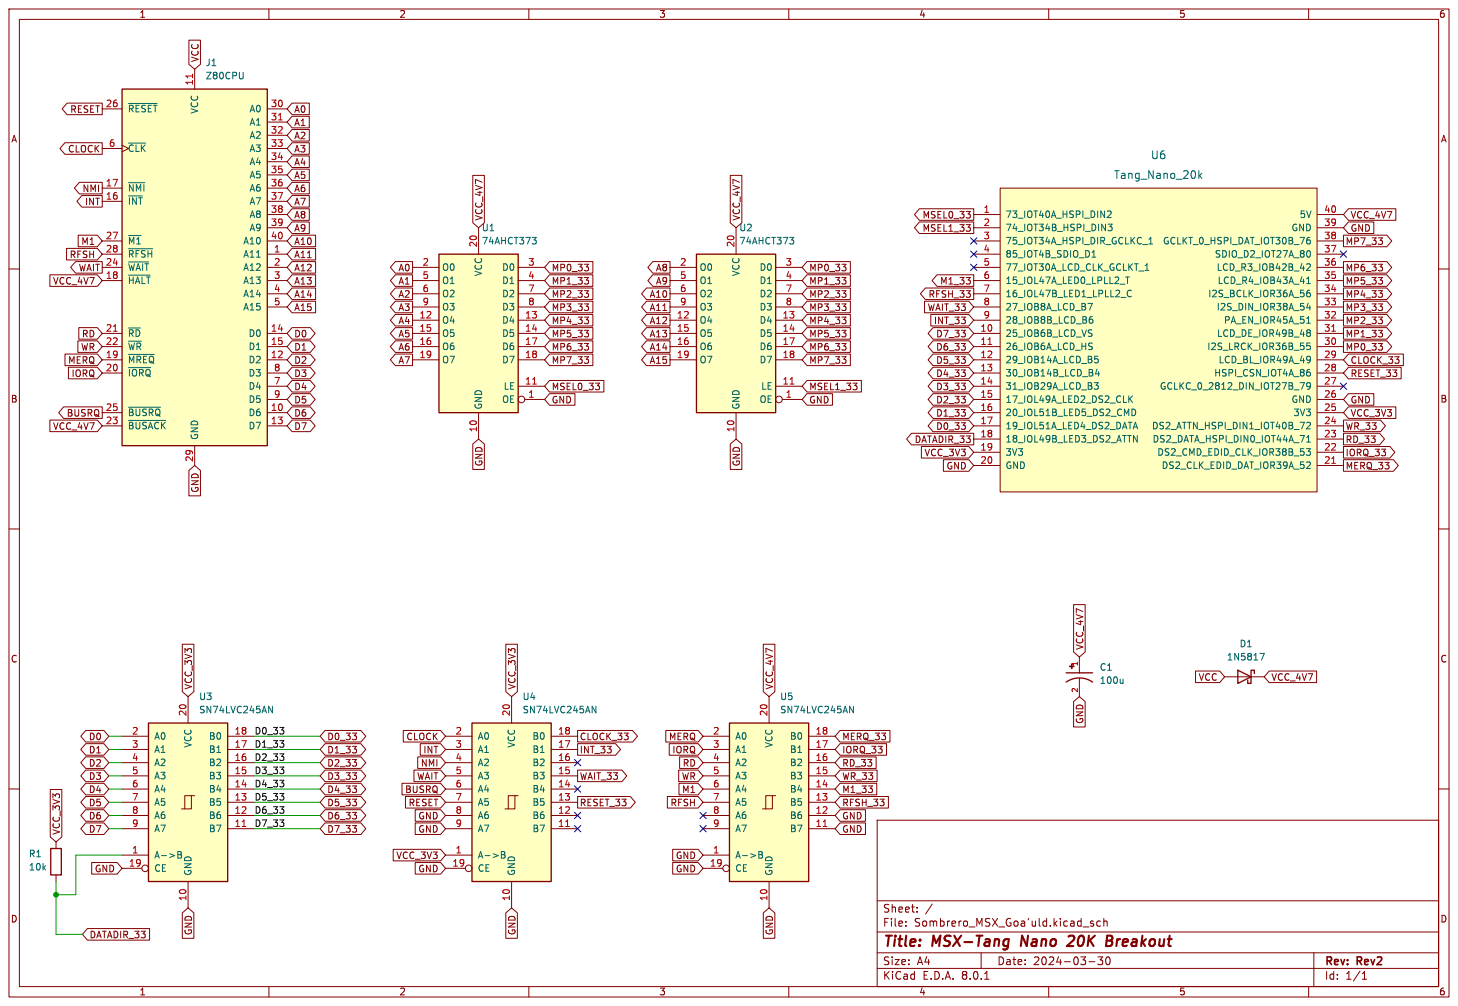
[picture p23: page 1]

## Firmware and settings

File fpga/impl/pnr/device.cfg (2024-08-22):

set JTAG regular_io = false
set SSPI regular_io = true
set MSPI regular_io = true
set READY regular_io = false
set DONE regular_io = false
set RECONFIG_N regular_io = false
set I2C regular_io = false
set CRC_check = true
set compress = false
set encryption = false
set security_bit_enable = true
set bsram_init_fuse_print = true
set background_programming = off
set secure_mode = false
set download_speed = 250/32
set program_done_bypass = false
set wake_up = 0
set format = binary
set power_on_reset_monitor = true
set multiboot_spi_flash_address = 0x00000000
set vccx = 3.3
set unused_pin = default

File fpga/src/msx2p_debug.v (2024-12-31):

module msx2p_debug(
    input clk_27m,
    input clk,
    input clk_enable,
    input reset_n,
	input [15:0] bus_addr,
    input [7:0] bus_data,
    input bus_iorq_n,
    input bus_mreq_n,
    input bus_wr_n,
    input send,

    output uart_tx,
    output boot_ok
);

    reg [31:0] counter_tic = 32'd0;
    wire tic;
    always @ (posedge clk_27m) begin
        counter_tic <= counter_tic + 1;
        if (counter_tic > 2700000) begin
            counter_tic <= 32'd0;
        end
    end
    assign tic = (counter_tic == 32'd0) ? 1: 0;

	reg [7:0] debug_state = 8'd0;
    reg [7:0] page23_slot_expanded = 8'd0;
    reg [7:0] primary_slot = 8'd0;
    reg [7:0] secondary_slot = 8'd0;
    reg[7:0] subrom_found = 8'd0;
    reg[7:0] rtc_found = 8'd0;

    always @(posedge clk or negedge reset_n) begin
		if (!reset_n) begin
			debug_state <= 8'd0;
            page23_slot_expanded <= 8'd0;
            primary_slot <= 8'd0;
            secondary_slot <= 8'd0;
            subrom_found <= 8'd0;
            rtc_found <= 8'd0;

        end else if (clk_enable == 1) begin
			case (debug_state)

				8'd00: begin //First byte
					if (bus_addr == 16'h0000 && bus_data == 8'hf3) begin
						debug_state <= debug_state + 1;
					end
				end
				8'd01: begin //Second byte
					if (bus_addr == 16'h0001 && bus_data == 8'hc3) begin
						debug_state <= debug_state + 1;
					end
				end
				8'd02: begin //Third byte
					if (bus_addr == 16'h0002 && bus_data == 8'h16) begin
						debug_state <= debug_state + 1;
					end
				end
				8'd03: begin //jp #0416
					if (bus_addr == 16'h0003 && bus_data == 8'h04) begin
						debug_state <= debug_state + 1;
					end
				end
				8'd04: begin 
					if (bus_addr == 16'h0416) begin //CHKRAM
						debug_state <= debug_state + 1;
					end
				end
				8'd05: begin //Select Slot 0
					if (bus_addr == 16'h0436) begin
						debug_state <= debug_state + 1;
					end
				end
				8'd06: begin //Page2: Slot 0 is expanded / not expanded
					if (bus_addr == 16'h044b) begin
                        page23_slot_expanded[4] <= 1;
						debug_state <= debug_state + 1;
					end
                    else if (bus_addr == 16'h0451) begin
                        debug_state <= debug_state + 1;
                    end
				end
				8'd07: begin //Select Slot 1
					if (bus_addr == 16'h0436) begin
						debug_state <= debug_state + 1;
					end
				end
				8'd08: begin //Page2: Slot 1 is expanded / not expanded
					if (bus_addr == 16'h044b) begin
                        page23_slot_expanded[5] <= 1;
						debug_state <= debug_state + 1;
					end
                    else if (bus_addr == 16'h0451) begin
                        debug_state <= debug_state + 1;
                    end
				end
				8'd09: begin //Select Slot 2
					if (bus_addr == 16'h0436) begin
						debug_state <= debug_state + 1;
					end
				end
				8'd10: begin //Page2: Slot 2 is expanded / not expanded
					if (bus_addr == 16'h044b) begin
                        page23_slot_expanded[6] <= 1;
						debug_state <= debug_state + 1;
					end
                    else if (bus_addr == 16'h0451) begin
                        debug_state <= debug_state + 1;
                    end
				end
				8'd11: begin //Select Slot 3
					if (bus_addr == 16'h0436) begin
						debug_state <= debug_state + 1;
					end
				end
				8'd12: begin //Page2: Slot 3 is expanded / not expanded
					if (bus_addr == 16'h044b) begin
                        page23_slot_expanded[7] <= 1;
						debug_state <= debug_state + 1;
					end
                    else if (bus_addr == 16'h0451) begin
                        debug_state <= debug_state + 1;
                    end
				end
				8'd13: begin //Select Slot 0
					if (bus_addr == 16'h04a2) begin
						debug_state <= debug_state + 1;
					end
				end
				8'd014: begin //Page3: Slot 0 is expanded / not expanded
					if (bus_addr == 16'h04ab) begin
                        page23_slot_expanded[0] <= 1;
						debug_state <= debug_state + 1;
					end
                    else if (bus_addr == 16'h04b4) begin
                        debug_state <= debug_state + 1;
                    end
				end
				8'd15: begin //Select Slot 1
					if (bus_addr == 16'h04a2) begin
						debug_state <= debug_state + 1;
					end
				end
				8'd016: begin //Page3: Slot 1 is expanded / not expanded
					if (bus_addr == 16'h04ab) begin
                        page23_slot_expanded[1] <= 1;
						debug_state <= debug_state + 1;
					end
                    else if (bus_addr == 16'h04b4) begin
                        debug_state <= debug_state + 1;
                    end
				end
				8'd17: begin //Select Slot 2
					if (bus_addr == 16'h04a2) begin
						debug_state <= debug_state + 1;
					end
				end
				8'd018: begin //Page3: Slot 2 is expanded / not expanded
					if (bus_addr == 16'h04ab) begin
                        page23_slot_expanded[2] <= 1;
						debug_state <= debug_state + 1;
					end
                    else if (bus_addr == 16'h04b4) begin
                        debug_state <= debug_state + 1;
                    end
				end
				8'd19: begin //Select Slot 3
					if (bus_addr == 16'h04a2) begin
						debug_state <= debug_state + 1;
					end
				end
				8'd020: begin //Page3: Slot 3 is expanded / not expanded
					if (bus_addr == 16'h04ab) begin
                        page23_slot_expanded[3] <= 1;
						debug_state <= debug_state + 1;
					end
                    else if (bus_addr == 16'h04b4) begin
                        debug_state <= debug_state + 1;
                    end
				end
				8'd21: begin //init2
					if (bus_addr == 16'h7b61) begin
						debug_state <= debug_state + 1;
					end
				end
				8'd22: begin //select primary slot RAM in page 2 and 3; out (#a8),a
					if (bus_addr == 16'h7b66) begin
						debug_state <= debug_state + 1;
					end
				end
				8'd23: begin //out (#a8),a
					if (bus_addr[7:0] == 8'hA8 && bus_iorq_n == 0 && bus_wr_n == 0) begin
                        primary_slot <= bus_data;
						debug_state <= debug_state + 1;
					end
				end
				8'd24: begin //select secundary slot RAM in page 2 and 3; ld (#ffff),a
					if (bus_addr == 16'h7b69) begin
						debug_state <= debug_state + 1;
					end
				end
				8'd25: begin //ld (#ffff),a
					if (bus_addr == 16'hffff && bus_mreq_n == 0 && bus_wr_n == 0) begin
                        secondary_slot <= bus_data;
						debug_state <= debug_state + 1;
					end
				end
				8'd26: begin //ldir - init ram
					if (bus_addr == 16'h7b78) begin
						debug_state <= debug_state + 1;
					end
				end
				8'd27: begin //Set EXPTBL
					if (bus_addr == 16'h7b7a) begin
						debug_state <= debug_state + 1;
					end
				end
				8'd28: begin //Set SSLTLP
					if (bus_addr == 16'h7B80) begin
						debug_state <= debug_state + 1;
					end
				end
				8'd29: begin //JP INIT3; JP #7C76
					if (bus_addr == 16'h7bbb) begin
						debug_state <= debug_state + 1;
					end
				end
				8'd30: begin //Init Basic
					if (bus_addr == 16'h7c76) begin
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

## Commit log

2023-09-17 Primera versión del hardware
    Hardware first version
    [Sombrero_MSX_Goa'uld-B_Mask.gbs, Sombrero_MSX_Goa'uld-B_Paste.gbp, Sombrero_MSX_Goa'uld-B_Silkscreen.gbo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]
2023-11-18 Version 0.5 V9958 + msx2+ + mapper + psg + scc + rtc
    [amplitude_calculator_for_ocm.ods, device.cfg, filter.xls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]
2023-11-18 fixed slot map
2023-11-20 Fixed, slot map, updated readme
2024-02-13 Removed NMI, BUSRQ pins to avoid overheating of U4 due to voltage >> 5V Fixed name 74HCT373
    [Sombrero_MSX_Goa'uld-B_Mask.gbs, Sombrero_MSX_Goa'uld-B_Paste.gbp, Sombrero_MSX_Goa'uld-B_Silkscreen.gbo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]
2024-02-13 Updated readme, slots map
2024-03-30 Added v2 Board
    [CAP.STEP, D_DO-15_P15.24mm_Horizontal.step, PinHeader_1x20_P2.54mm_Vertical.step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]
2024-04-09 Version 0.2 Reduced features to increase stability, compatibility *Z80: kept *V9958: kept, removed 50 Hz support *MSX2+ bios: kept, removed logo *RTC: kept *Mapper: removed *PSG, SCC, FM: removed
    [amplitude_calculator_for_ocm.ods, device.cfg, filter.xls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]
2024-04-09 Updated slots map
2024-06-04 Roll back to version 0.61, more stable
    [amplitude_calculator_for_ocm.ods, device.cfg, filter.xls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]
2024-08-22 * Version 0.74 Included pin for double buffer hardware Cleaned redundant code in ppi and megaram Removed bus_rfsh_n in _req signals Reduced demux bits Fixed SCC sound Removed bus_data filter
    [device.cfg]
2024-08-22 * Version 0.74 Included pin for double buffer hardware Cleaned reduntant code in ppi and megaram Removed bus_rfsh_n in _req signals Reduced demux bits Fixed SCC sound Removed bus_data filter
2024-09-05 Added v4 Prototype
    [MSX_Goauld_Rev4-B_Mask.gbs, MSX_Goauld_Rev4-B_Paste.gbp, MSX_Goauld_Rev4-B_Silkscreen.gbo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]
2024-09-06 Updated readme with V4 board
2024-09-22 Version 0.75 (95,RC4) *Replaced modul t80a -> g80a *Fixed issue, demux logic could ring *Changed parameters, TP, TON in demux *Improved filter, pin ex_bus_int_n *Moved Megaram-SCC to slot 0-2, freein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
2024-09-22 Updated picture, slot map
2024-10-12 * Version 0.76 (95,RC3) -Included configuration -Fixed glitch in boot logo
    [top.v]
2024-10-29 readme: add errata for rev4 board
2024-11-01 HW Version 1.4 -Included resistor array -Replaced U1, U2 -> 74HC373, U5 -> 74HC245 -Removed capacitor, resistor -Reduced size
    [PinSocket_2x06_P2.54mm_Vertical.step, Qmtech_xc7a15t_35t.step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]
2024-11-18 Version 0.78 (95,RC2) *Updated boot menu, thank you nataliapc *Created option to move megaram *Created feature ghost scc *Updated feature megaram <-> scc *Created feature switched ports *Updated code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
2024-12-05 Added v4.1 gerbers
    [MSX_Goauld_Rev4_1-B_Mask.gbs, MSX_Goauld_Rev4_1-B_Paste.gbp, MSX_Goauld_Rev4_1-B_Silkscreen.gbo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]
2024-12-14 Included pcb, goauld 1.4_smd Updated readme
    [PinSocket_2x06_P2.54mm_Vertical.step, Qmtech_xc7a15t_35t.step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]
2024-12-31 Version FW 0.80 *Removed megaram *Removed sd support *Updated timing constraints *Fixed bug demux *Included debug module *Included option ENABLE_V9958 *Updated menú
    [msx2p_debug.v, top.v]

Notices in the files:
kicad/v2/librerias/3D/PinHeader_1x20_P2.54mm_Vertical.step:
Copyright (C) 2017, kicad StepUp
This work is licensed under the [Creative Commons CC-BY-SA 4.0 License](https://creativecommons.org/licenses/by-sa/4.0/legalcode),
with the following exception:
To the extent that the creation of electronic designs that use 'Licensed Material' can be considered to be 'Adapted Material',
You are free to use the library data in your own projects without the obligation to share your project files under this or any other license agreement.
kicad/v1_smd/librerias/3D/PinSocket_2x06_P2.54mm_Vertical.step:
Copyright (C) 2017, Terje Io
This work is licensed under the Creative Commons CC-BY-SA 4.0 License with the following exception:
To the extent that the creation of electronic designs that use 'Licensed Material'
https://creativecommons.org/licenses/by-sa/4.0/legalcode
